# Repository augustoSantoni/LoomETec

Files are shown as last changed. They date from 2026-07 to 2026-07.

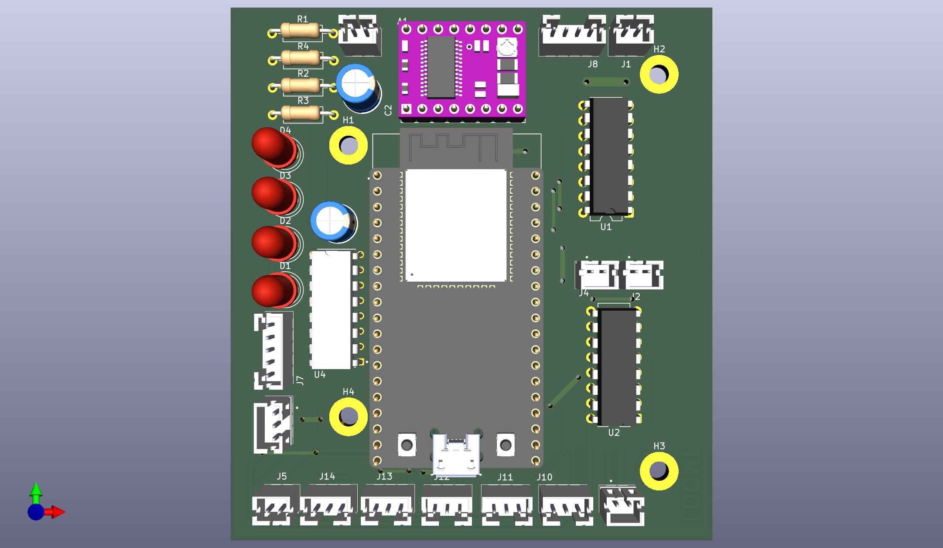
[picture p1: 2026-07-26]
Archivos/PCB/Archivos/LoomETec.png

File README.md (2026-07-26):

# 🧶 LOOM ETEC - Telar Automático con Sistema Jacquard





## 📖 Descripción del Proyecto

El proyecto **LOOM ETEC** se desarrolla en el marco del taller **AeroGlobETec**, que combina disciplinas como ciencias, electrónica, informática, mecánica y dibujo técnico.

### 🎯 Motivación

Este proyecto nace de una motivación personal, inspirada en la memoria de mi abuela, quien dedicó gran parte de su vida a tejer y donar sus creaciones a quienes más lo necesitaban. Tras su fallecimiento, surgió la idea de conmemorar su legado mediante la creación de un telar automático que perpetúe su espíritu altruista e integre conocimientos técnicos.

**Objetivo principal**: Automatizar el proceso de tejido para producir mantas destinadas a instituciones que asisten a recién nacidos en situación de vulnerabilidad.

### 🏗️ Tipos de Telares Implementados

#### 1️⃣ Telar Convencional

Compuesto por cuatro partes esenciales:

- **Caladores**: Varillas que levantan o bajan selectivamente los hilos de la urdimbre, creando una abertura (llamada "calada") por donde pasa la lanzadera con el hilo de la trama.
- **Peine**: Herramienta dentada que presiona y compacta el hilo de la trama después de cada pasada de la lanzadera.
- **Lanzadera**: Dispositivo que transporta el hilo de la trama a través de los hilos de la urdimbre para tejer la tela.
- **Plegador**: Mecanismo que enrolla la tela tejida, manteniendo la tensión y avanzando la urdimbre a medida que se teje.

#### 2️⃣ Telar Jacquard (31 columnas)

Una reversión del telar de Jacquard, máquina textil que utiliza patrones digitales (en lugar de tarjetas perforadas) para controlar automáticamente el levantamiento individual de hilos de urdimbre, permitiendo la creación de patrones complejos.

**Sistema de control**:
- **Eje X**: Motor PAP para movimiento horizontal (31 posiciones)
- **Eje Z**: Servomotor para selección arriba/abajo de cada hilo
- **Eje Y**: Motor DC para elevación del cabezal (calada)

---

## 🛠️ Tecnologías Utilizadas

### Software

#### **PlatformIO**
IDE profesional para desarrollo de sistemas embebidos. Proporciona gestión de bibliotecas, compilación cruzada y soporte para múltiples plataformas de hardware. Utilizado para programar el ESP32 con C++.

#### **Node-RED**
Herramienta de programación visual basada en flujos para conectar dispositivos IoT. Actúa como middleware entre la interfaz web y el broker MQTT, procesando las peticiones HTTP y transformándolas en comandos MQTT.

#### **MQTT (Mosquitto/HiveMQ Cloud)**
Protocolo de mensajería ligero para IoT. Permite la comunicación asíncrona entre el ESP32 y el servidor mediante topics (tópicos). Se puede usar Mosquitto localmente o HiveMQ Cloud para acceso remoto.

#### **Autodesk Fusion 360**
Software de modelado 3D CAD/CAM utilizado para diseñar las piezas mecánicas del telar, incluyendo soportes, engranajes y estructuras.

#### **Python 3.x + Tkinter**
Lenguaje de programación utilizado para desarrollar el **Editor de Trama**, una aplicación de escritorio que permite crear patrones de tejido de forma visual mediante una interfaz gráfica.

### Hardware

| Componente | Descripción | Cantidad |
|---|---|---|
| **ESP32 DevKit V1** | Microcontrolador principal con WiFi y Bluetooth integrado | 1 |
| **Motores DC** | Para lanzadera, peine y eje Y (elevación) | 3-4 |
| **Servomotores** | Para selección de hilos (Eje Z) en sistema Jacquard | 1 |
| **Motores PAP + DVR8825** | Motor paso a paso con driver para eje X (horizontal) y plegador | 2 |
| **Puente H L298N** | Controlador para motores DC bidireccionales | 2-3 |
| **Sensores Fin de Carrera** | Detección de posiciones límite (mínimo 7) | 7+ |
| **Fuente de Alimentación** | 12V 5A para motores | 1 |
| **Cables y Conectores** | Jumpers, borneras, conectores Dupont | Varios |

---

## 📋 Requisitos Previos

### Software a Instalar

1. **Visual Studio Code** con extensión **PlatformIO IDE**
2. **Node.js** (v14 o superior) para Node-RED
3. **Python 3.8+** para el Editor de Trama
4. **Mosquitto MQTT Broker** (opcional, para pruebas locales)

---

## 🚀 Guía de Instalación

### 1. Instalación de PlatformIO

1. Descargar e instalar [Visual Studio Code](https://code.visualstudio.com/)
2. Abrir VS Code y dirigirse a **Extensions** (Ctrl+Shift+X)
3. Buscar **PlatformIO IDE** e instalar
4. Reiniciar VS Code
5. Verificar instalación: debería aparecer un ícono de hormiga en la barra lateral

### 2. Instalación de Node-RED

```bash
# Instalar Node.js desde https://nodejs.org/

# Instalar Node-RED globalmente
npm install -g node-red

# Instalar nodos adicionales necesarios
cd ~/.node-red
npm install node-red-dashboard
npm install node-red-contrib-mqtt-broker

# Iniciar Node-RED
node-red

# Acceder a http://localhost:1880
```

### 3. Instalación de Python y Dependencias

```bash
# Verificar instalación de Python
python --version

# Instalar dependencias del Editor de Trama
pip install pillow
pip install tk

# En Linux/Mac, puede ser necesario instalar tkinter:
sudo apt-get install python3-tk  # Ubuntu/Debian
```

### 4. Configuración de MQTT Broker

#### Opción A: Mosquitto Local

```bash
# Windows: Descargar desde https://mosquitto.org/download/
# Linux:
sudo apt-get install mosquitto mosquitto-clients

# Iniciar servicio
sudo systemctl start mosquitto
sudo systemctl enable mosquitto

# Verificar que está corriendo en puerto 1883
netstat -tuln | grep 1883
```

#### Opción B: HiveMQ Cloud (Recomendado para acceso remoto)

1. Crear cuenta gratuita en [HiveMQ Cloud](https://www.hivemq.com/mqtt-cloud-broker/)
2. Crear un nuevo cluster
3. Anotar credenciales (URL, puerto, usuario, contraseña)
4. Actualizar configuración en `main.cpp` y flujos de Node-RED

---

## 🎨 Editor de Trama - Guía de Uso

### Iniciar el Editor

```bash
python Editor-Trama.py
```

### Funcionalidades Principales

#### 1. Crear un Patrón

- **Tamaño**: El editor trabaja con una cuadrícula de 24x24 píxeles por defecto
- **Colores**: 
  - Negro (patrón activo)
  - Blanco (fondo)
- **Pintar**: Click izquierdo para pintar, click derecho para borrar

#### 2. Pinceles Disponibles

| Pincel | Descripción |
|---|---|
| Punto | Pinta un solo píxel |
| Línea H | Línea horizontal de 3 píxeles |
| Línea V | Línea vertical de 3 píxeles |
| Cruz | Forma de cruz (5 píxeles) |
| Cuadrado | Cuadrado de 2x2 |
| Diagonal | Diagonal de 3x3 |

**Crear pincel personalizado**:
1. Click en "Crear Pincel"
2. Definir dimensiones (ej: 3x3)
3. Click en "Generar Cuadrícula"
4. Pintar el patrón deseado
5. "Guardar Pincel" → ingresar nombre → guardar archivo `.brush`

#### 3. Ajustar Tamaño del Lienzo

- **Agrandar**: Ctrl/Cmd + `+` o botón "Agrandar" (incrementa 4 filas)
- **Achicar**: Ctrl/Cmd + `-` o botón "Achicar" (reduce 4 filas, mínimo 24)

#### 4. Replicar Diseño

1. Crear un patrón base en las primeras 24 filas
2. Ingresar número de repeticiones (ej: 3)
3. Click en "Aplicar Replicación"
4. El patrón se repetirá verticalmente

#### 5. Exportar Patrón

##### Guardar como PNG (Ctrl/Cmd + S)
- Genera imagen con franjas de sincronización (patrón ajedrezado)
- Formato: 1 píxel = 1 hilo
- Incluye franjas cada 4 filas/columnas para alineación

##### Guardar como JSON (Ctrl/Cmd + J)
```json
{
  "dimensiones": [31, 100],
  "datos": [
    [0, 1, 0, 1, ...],
    [1, 0, 1, 0, ...],
    ...
  ]
}
```
- **IMPORTANTE**: Para el telar Jacquard, el patrón debe tener exactamente **31 columnas**
- 0 = hilo abajo (blanco), 1 = hilo arriba (negro)

#### 6. Atajos de Teclado

| Atajo | Acción |
|---|---|
| Ctrl/Cmd + Z | Deshacer |
| Ctrl/Cmd + Y | Rehacer |
| Ctrl/Cmd + L | Limpiar lienzo |
| Ctrl/Cmd + S | Guardar PNG |
| Ctrl/Cmd + J | Guardar JSON |
| Ctrl/Cmd + `+` | Agrandar lienzo |
| Ctrl/Cmd + `-` | Achicar lienzo |

---

## ⚡ Puesta en Marcha del Telar

### Paso 1: Conexiones del ESP32

#### Telar Convencional

```
LANZADERA:
  enaLanzadera → GPIO 29 (PWM)
  lanzadera1 → GPIO 28 (dirección 1)
  lanzadera2 → GPIO 20 (dirección 2)
  fdcLanzadera1 → GPIO 40 (fin de carrera izq)
  fdcLanzadera2 → GPIO 15 (fin de carrera der)

CALADORES:
  enaCaladores → GPIO 34 (PWM)
  caladores1 → GPIO 35 (subir)
  caladores2 → GPIO 27 (bajar)
  fdcCaladores → GPIO 16 (fin de carrera)

PEINE:
  enaPeine → GPIO 22 (PWM)
  peine1 → GPIO 24 (adelante)
  peine2 → GPIO 23 (atrás)
  fdcPeine1 → GPIO 13 (fin de carrera adelante)
  fdcPeine2 → GPIO 14 (fin de carrera atrás)

PLEGADOR:
  stepPlegador → GPIO 8 (pulsos)
  dirPlegador → GPIO 18 (dirección)
```

#### Telar Jacquard (adicional al convencional)

```
EJE X (Motor PAP):
  stepEjeX → GPIO 25
  dirEjeX → GPIO 26
  fdcEjeX_Home → GPIO 17 (posición inicial)

EJE Z (Servo):
  servoEjeZ → GPIO 19

EJE Y (Motor DC elevación):
  enaEjeY → GPIO 34 (PWM)
  ejeY_Up → GPIO 35
  ejeY_Down → GPIO 27
  fdcEjeY_Arriba → GPIO 16
  fdcEjeY_Abajo → GPIO 21
```

#### Diagrama de Conexión Puente H (ejemplo L298N)

```
ESP32           L298N          Motor DC
GPIO XX   →     ENA      →     (PWM control velocidad)
GPIO YY   →     IN1      →     (dirección)
GPIO ZZ   →     IN2      →     (dirección)
              OUT1/OUT2  →     Motor
GND       →     GND
12V       →     12V (fuente externa)
```

#### Conexión DVR8825 (Motor PAP)

```
ESP32           DVR8825        Motor PAP
GPIO XX   →     STEP
GPIO YY   →     DIR
             →  ENABLE (a GND o control)
12V fuente →    VMOT
GND        →    GND
             →  A1, A2, B1, B2 → Bobinas del motor
```

### Paso 2: Programar el ESP32

```bash
# Clonar el repositorio
git clone https://github.com/tu-usuario/loom-etec.git
cd loom-etec

# Abrir el proyecto en VS Code con PlatformIO
code .

# Configurar WiFi y MQTT en main.cpp (líneas 50-54)
String ssid = "TU_WIFI";
String password = "TU_PASSWORD";
const char* mqtt_server = "TU_BROKER_IP";  # localhost o IP de HiveMQ
const char* mqtt_user = "usuario";
const char* mqtt_pass = "contraseña";

# Compilar y subir (en VS Code)
# Click en el ícono "→" (PlatformIO: Upload) en la barra inferior
# O usar el atajo: Ctrl+Alt+U

# Monitorear salida serial
# Click en el ícono de enchufe (PlatformIO: Serial Monitor)
# O atajo: Ctrl+Alt+S
```

### Paso 3: Configurar Node-RED

```bash
# Iniciar Node-RED
node-red

# Abrir navegador en http://localhost:1880
```

#### Importar Flujo

1. Click en menú hamburguesa (☰) → **Import**
2. Seleccionar archivo:
   - `node-red-flujo-telar.json` (telar Jacquard con carga de patrón)
   - O `node-red-flujo-telar-simple.json` (telar convencional)
3. Click en **Import**

#### Configurar Broker MQTT en Node-RED

1. Doble click en cualquier nodo MQTT (ej: "mqtt_empezar")
2. Click en el lápiz junto a "Server"
3. Configurar:
   ```
   Server: localhost  (o IP del broker)
   Port: 1883
   Username: tu_usuario
   Password: tu_contraseña
   ```
4. Click en **Update** → **Done**
5. Click en **Deploy** (botón rojo arriba a la derecha)

#### Verificar Endpoints HTTP

Una vez desplegado, los siguientes endpoints estarán disponibles:

```
POST http://localhost:1880/api/empezar       - Iniciar tejido
POST http://localhost:1880/api/parar         - Detener tejido
POST http://localhost:1880/api/config/red    - Configurar WiFi
POST http://localhost:1880/api/config/patron - Cargar patrón JSON (solo Jacquard)
GET  http://localhost:1880/api/vueltas       - Obtener contador de vueltas
```

### Paso 4: Interfaz Web

#### Opción 1: Servidor Local Simple

```bash
# Navegar a la carpeta del proyecto
cd loom-etec

# Iniciar servidor HTTP simple con Python
python -m http.server 8000

# Abrir navegador en:
http://localhost:8000/index.html
```

#### Opción 2: Servidor Web Externo

Subir el archivo `index.html` a cualquier hosting web o usar:

```bash
# Con Node.js (live-server)
npm install -g live-server
live-server --port=8000
```

### Paso 5: Operación del Sistema

#### Para Telar Convencional

1. Verificar que el ESP32 esté conectado a WiFi (revisar Serial Monitor)
2. Abrir interfaz web en `http://localhost:8000/index.html`
3. Verificar conexión:
   - Debe mostrar vueltas: 0
   - Botones deben estar habilitados
4. Click en **▶ Iniciar** para comenzar tejido
5. El telar ejecutará la secuencia automáticamente
6. Click en **■ Detener** para pausar

#### Para Telar Jacquard

1. Crear patrón en Editor de Trama (31 columnas)
2. Exportar como JSON (Ctrl+J)
3. Abrir interfaz web
4. En "Cargar patrón":
   - Click en zona de arrastre o seleccionar archivo
   - Elegir el archivo `.json` generado
   - Click en **Subir patrón al telar**
   - Esperar confirmación "🟢 Patrón subido correctamente"
5. Click en **▶ Iniciar**
6. El telar ejecutará el patrón columna por columna

---

## 🔧 Calibración y Ajustes

### Calibración del Sistema Jacquard

En `main.cpp`, ajustar las siguientes constantes según tu hardware:

```cpp
// Línea 60-65
#define PASOS_POR_COLUMNA 200    // Ajustar según distancia entre columnas
#define DELAY_PASO_X 800         // Velocidad del motor PAP (microsegundos)
#define SERVO_POS_ABAJO 45       // Posición servo para dejar hilo abajo
#define SERVO_POS_ARRIBA 135     // Posición servo para fijar hilo arriba
#define SERVO_DELAY 150          // Tiempo de movimiento del servo
```

### Ajuste de Velocidades de Motores

```cpp
// Línea 115-120
ledcWrite(PWM_LANZADERA, 200);  // 0-255: ajustar velocidad lanzadera
ledcWrite(PWM_PEINE, 200);      // 0-255: ajustar velocidad peine
ledcWrite(PWM_EJE_Y, 200);      // 0-255: ajustar velocidad elevación
```

### Tiempos de Estabilización

```cpp
// Línea 70-75
#define DELAY_TEJER 500           // Pausa entre ciclos completos
#define TIEMPO_ESTABILIDAD 200    // Pausa tras cada movimiento
#define TIEMPO_ESPERA_FDC 15000   // Timeout para sensores de fin de carrera
```

---

## 📡 Arquitectura del Sistema

```
┌─────────────────┐
│  Interfaz Web   │ ← Usuario interactúa
│  (index.html)   │
└────────┬────────┘
         │ HTTP (fetch)
         ▼
┌─────────────────┐
│   Node-RED      │ ← Middleware (localhost:1880)
│  (flujo.json)   │
└────────┬────────┘
         │ MQTT
         ▼
┌─────────────────┐
│ Broker MQTT     │ ← Mosquitto/HiveMQ
│  (puerto 1883)  │
└────────┬────────┘
         │ WiFi
         ▼
┌─────────────────┐
│     ESP32       │ ← Control de hardware
│   (main.cpp)    │
└────────┬────────┘
         │ GPIO
         ▼
┌─────────────────┐
│ Motores/Sensores│ ← Sistema mecánico
└─────────────────┘
```

---

## 🐛 Solución de Problemas

### ESP32 no se conecta a WiFi

```cpp
// Verificar credenciales en main.cpp
String ssid = "NOMBRE_EXACTO";  // Sin espacios extra
String password = "PASSWORD_EXACTA";

// Verificar en Serial Monitor:
// - "Conectando a SSID..."
// - "WiFi conectado"
// - "IP: xxx.xxx.xxx.xxx"
```

### Node-RED no recibe mensajes MQTT

1. Verificar broker MQTT está corriendo:
   ```bash
   sudo systemctl status mosquitto
   # o
   mosquitto -v
   ```

2. Probar conexión con mosquitto_sub:
   ```bash
   mosquitto_sub -h localhost -t "empezar" -v
   ```

3. Verificar configuración de broker en Node-RED coincide con ESP32

### Sensores de fin de carrera no funcionan

```cpp
// Verificar lógica de activación (línea 30)
#define FDC_PRESIONADO LOW  // Cambiar a HIGH si usa pull-down

// Agregar resistencias pull-up/down según tipo de sensor
```

### Servo no se mueve correctamente

```cpp
// Calibrar posiciones del servo (línea 62-63)
#define SERVO_POS_ABAJO 45      // Probar valores entre 0-180
#define SERVO_POS_ARRIBA 135    // Ajustar según rango del servo

// Verificar alimentación del servo (5V, GND correcto)
```

### Motor PAP pierde pasos

```cpp
// Aumentar delay entre pasos (línea 61)
#define DELAY_PASO_X 1200  // Valor más alto = movimiento más lento pero preciso

// Verificar:
// - Conexión de bobinas del motor
// - Configuración de micropasos en DVR8825
// - Alimentación suficiente (12V)
```

---

## 📊 Tópicos MQTT

### Publicados por ESP32

| Tópico | Payload | Descripción |
|---|---|---|
| `vuelta` | Número entero | Contador de vueltas completadas |

### Suscritos por ESP32

| Tópico | Payload | Descripción |
|---|---|---|
| `empezar` | `"1"` | Iniciar tejido |
| `parar` | `"1"` | Detener tejido |
| `config/red` | JSON: `{"ssid": "...", "password": "..."}` | Configurar WiFi |
| `config/patron` | JSON: `{"filename": "...", "content": "{...}"}` | Cargar patrón (Jacquard) |

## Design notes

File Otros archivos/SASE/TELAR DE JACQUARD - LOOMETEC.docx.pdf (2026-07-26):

LOOMETEC: TELAR DE JACQUARD SANTONI, Augusto - a.santoni@alumno.etec.um.edu.ar - 3ro Electrónica FURCI, Patricia Elizabeth - patricia.furci@etec.um.edu.ar - Docente a cargo.

### 1. INTRODUCCIÓN:

El proyecto se desarrolla en el marco
del taller AeroGlobETec que combina
disciplinas | como | ciencias, | electrónica,
informática, mecánica y dibujo técnico.

El presente proyecto nace de la motivación de automatizar el proceso de tejido para producir mantas destinadas a instituciones que asisten a recién nacidos en situación de vulnerabilidad, con el propósito de contribuir solidariamente a quienes más lo necesitan.

A diferencia de un telar de calado simple, este proyecto implementa un sistema inspirado en el mecanismo Jacquard, que permite un control selectivo e individual de los hilos de la urdimbre. En lugar de tarjetas perforadas, se emplea un sistema de movimiento en tres ejes: uno que recorre los soportes de hilos, otro que selecciona cuáles serán elevados en la próxima calada y aquel que los eleva, posibilitando la generación de patrones complejos de manera automatizada.

Un telar convencional se compone de cuatro partes esenciales: Caladores: varillas que levantan o bajan selectivamente los hilos de la urdimbre, creando la "calada". Peine: herramienta dentada que compacta el hilo de la trama tras cada pasada. Lanzadera: dispositivo que transporta el hilo de la trama. Plegador: mecanismo que enrolla la tela tejida manteniendo la tensión.

### 2. OBJETIVOS:

Objetivos generales:
El objetivo central es materializar el telar automático y dejarlo en pleno funcionamiento, incorporando además una aplicación de escritorio para el diseño de patrones y un sistema de control de procesos en tiempo real. El desarrollo se plantea en etapas: primero en modo de calado simple y luego en modo de calado selectivo.
Objetivos específicos:
Adquirir un conocimiento profundo sobre el funcionamiento de los telares de Jacquard, comprendiendo cada una de sus
partes | y | su | integración. | Dominar
herramientas como Autodesk Fusion 360 para el diseño tridimensional y PlatformIO en Visual Studio Code para el desarrollo del firmware. El sistema será controlado por un microcontrolador ESP32 NODEMCU-32S, y se desarrollará una PCB propia que integrará: dos motores PAP Nema 17 con drivers DRV8825 (soporte de hilos y plegador); un motor 28BYJ-48 con módulo ULN2003 y un micro servo sg90 (selección de hilos); cuatro motores DC con L293D (lanzadera, calador y peine); un convertidor step-down para operar con una única fuente de 12 V; y seis fines de carrera. La
comunicación | y | control | remoto | se
gestionarán mediante el broker Mosquitto, protocolo MQTT y Node-RED, conectado a una interfaz web. Se incorporará también un sistema de control de procesos basado en el ATmega328P y una aplicación de escritorio para el diseño de patrones de tejido.

### 3. DESARROLLO:

Primero se investigó en profundidad el funcionamiento del telar e idearon los sistemas correspondientes a cada una de sus partes. Para movimientos con límites precisos se emplearon motores DC con finales de carrera; para posicionamiento controlado, motores PAP o servomotores. Se realizaron diagramas técnicos de cada sistema de movimiento.

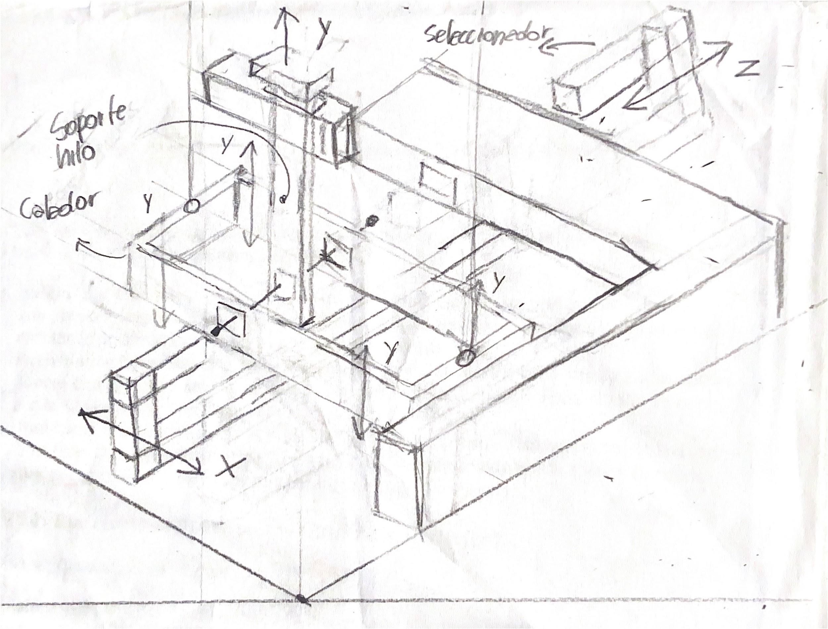
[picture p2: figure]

Diagrama del calador con sus respectivas partes y los ejes de movimiento
El sistema electrónico fue diseñado y desarrollado en su totalidad. Se elaboró el esquemático y el layout de una PCB que centraliza el control del telar, integrando todos los drivers y módulos.

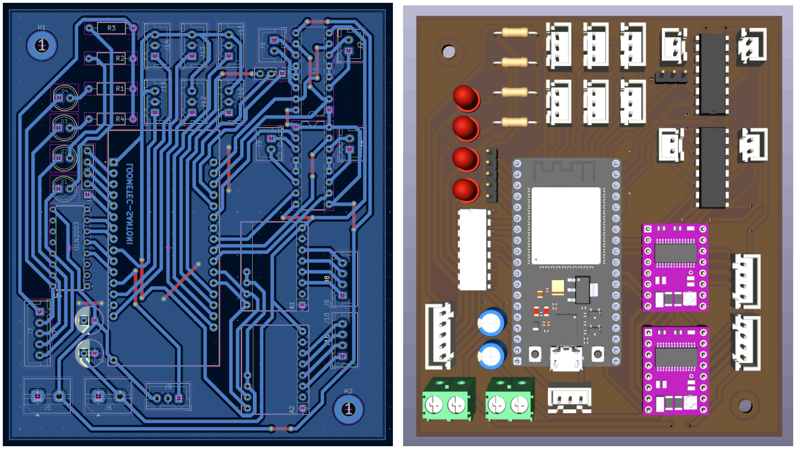
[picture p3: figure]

Prototipo de la placa para el telar
El | firmware | se | desarrolló | en
PlatformIO, implementando comunicación MQTT con broker Mosquitto, integrado con Node-RED y una interfaz web de monitoreo y control remoto. Donde se mantendrá un registro histórico de variables del proceso (patrón utilizado, centímetros producidos, fecha y hora) para facilitar el diagnóstico de fallas.

Se desarrolló una aplicación de escritorio (PC) para el diseño de patrones de tejido. La herramienta permite construir gráficamente una cuadrícula que define qué hilos de la urdimbre serán elevados en cada pasada. Al exportar, el sistema aplica
automáticamente | restricciones | de
estabilidad estructural que garantizan la cohesión de la tela resultante sin intervención del usuario. El patrón validado se exporta en formato JSON, listo para ser interpretado por el firmware del telar.

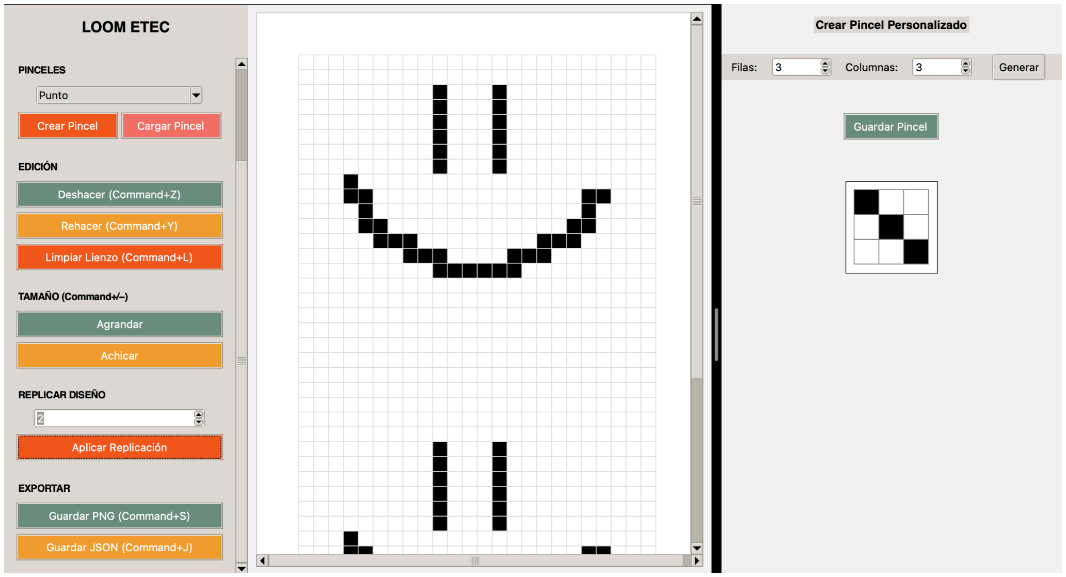
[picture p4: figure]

Interfaz del editor de trama junto con el editor de pinceles

Se proyecto un sistema de gestión de procesos basado en el ATmega328P, con sensores de tensión del hilo (FSR),
temperatura | (NTC/DHT) | y | humedad
ambiente (DHT) para implementarlo en el futuro. Cuando un parámetro supera el umbral definido, el sistema generaría alertas simultáneas en la interfaz Node-RED y mediante un bot de Telegram, permitiendo respuesta inmediata incluso de forma remota.

En Autodesk Fusion 360 se realizaron
los | modelos | 3D | correspondientes,
adaptables al sistema electrónico. Y una animación del funcionamiento del nuevo mecanismo basado en el sistema de Jacquard.

### 4. RESULTADOS:

- Diseño completo de la PCB con todos sus componentes integrados.

- Sistema de comunicación MQTT con Mosquitto, Node-RED e interfaz web para control remoto.
- Aplicación de escritorio para diseño de patrones con exportación en JSON y
restricciones | automáticas | de
estabilidad estructural.
- Ideación de un sistema de monitoreo
con | ATmega328P, | sensores FSR,
NTC/DHT y alertas vía Node-RED y
Telegram | para | su | futura
implementacion.
- Modelo tridimensional completo de la parte mecánica del telar y animación del funcionamiento del sistema de jacquard y del telar simple. A las cuales se puede acceder desde el siguiente link: Animaciónes-Telar. (https://drive.google.com/drive/folders/128MVLVmaG0PWlYvmhCZqHiCv8H61GHJZ?usp=sharing)

### 5. DISCUSIONES Y CONCLUSIONES:

El mayor desafío del proyecto ha sido la articulación entre el diseño y la materialización. Si bien el sistema completo —electrónico, informático y estructural— ha sido desarrollado y documentado en detalle, la concreción física del telar depende de la financiación que actualmente se está gestionando. Es esperable que, una vez materializado, el telar presente fallas e inconvenientes que deberán identificarse y corregirse de forma iterativa, siendo este proceso de ajuste una parte natural e inevitable del desarrollo de cualquier sistema de esta complejidad.

Como proyección futura, se propone la aplicación material del sistema de control de procesos ya ideado; ampliar la aplicación de patrones con simulación visual de la tela resultante, edición de diseños JSON previamente exportados y envío directo del patrón al telar desde la aplicación. Además, se contempla una interfaz web más completa con gestión de patrones remota, calibración automática de la tensión del hilo al inicio de cada sesión y un modo de prueba de patrón en seco para validar diseños antes de tejer, reduciendo el desperdicio de material.

En conclusión, esta experiencia ha
sido | altamente | enriquecedora,
proporcionando herramientas valiosas y un aprendizaje significativo. Poder pasar de una idea a un proyecto y encaminarse a concretar una máquina capaz de tejer mantas para
quienes | más | las | necesitan es una
oportunidad incomparable.

### 6. FUENTES:

[1] JANDER, R. (s.f.). R. Jander's personal
website. | Recuperado | de
https://r.jander.me.uk/
[2] TEXTALKS. (s.f.). Textalks YouTube
channel. | Recuperado | de
https://www.youtube.com/@textalks
[3] EDMUNDS, Susan T. (2020). Picturing Homeric Weaving. The Center for Hellenic
Studies. | Recuperado | de
https://chs.harvard.edu/susan-t-edmunds-picturing-homeric-weaving/
[4] TOMASZ ZAJĄC (31 ene 2013). LEGO Mindstorms NXT Loom Machine. Disponible en:
https://youtu.be/IPIJsdvDjsc?si=PrbSpxk5nL Od-ASY
[5] ¿CÓMO SE ELABORÓ? TEJIDO JACQUARD (https://www.youtube.com/watch?v=K6NgMNvK52A) , canal de YouTube del Museo Victoria y Alberto, 8 de octubre de 2015.
[6] PATRONES DE PROGRAMACIÓN: LA
HISTORIA | DEL | TELAR | JACQUARD, (https://www.scienceandindustrymuseum.org.uk/objects-and-stories/jacquard-loom)
publicación | del Science and Industry
Museum (Museo de Ciencia e Industria) de Manchester, 25 de junio de 2019.

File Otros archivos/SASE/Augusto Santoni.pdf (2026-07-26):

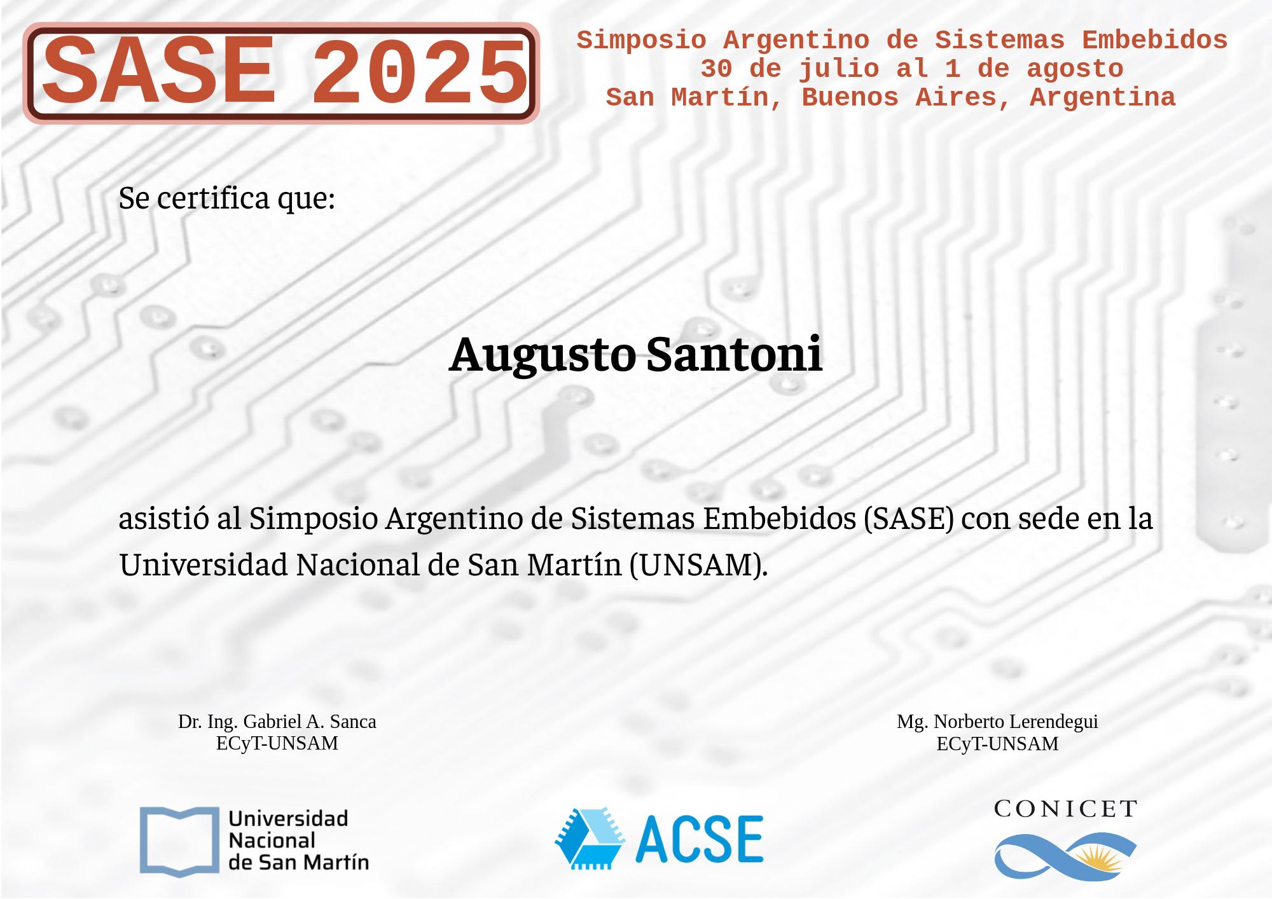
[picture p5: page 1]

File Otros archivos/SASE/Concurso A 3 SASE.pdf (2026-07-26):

“Proyectos de asignaturas de estudiantes de nivel secundario.

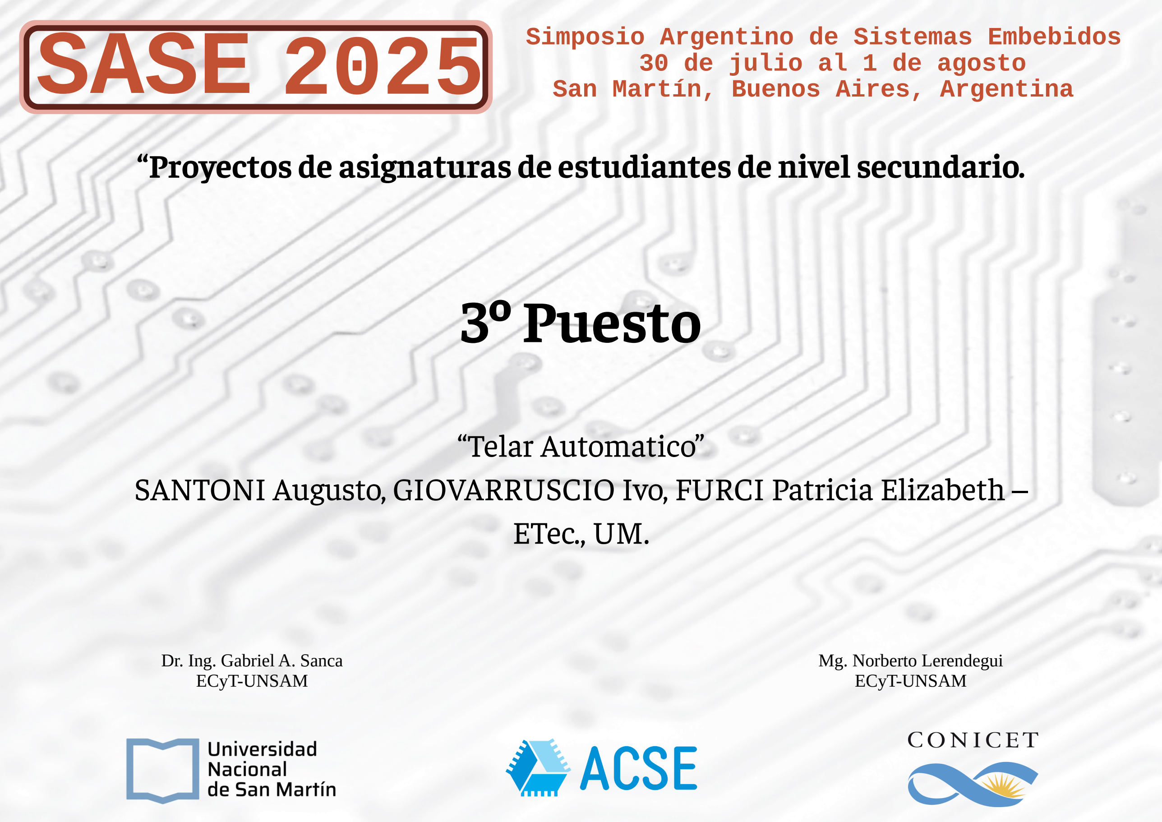
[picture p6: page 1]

Mg. Norberto Lerendegui
ECyT-UNSAM

Dr. Ing. Gabriel A. Sanca
ECyT-UNSAM
Simposio Argentino de Sistemas Embebidos SASE 2025 | 30 de julio al 1 de agosto

San Martín, Buenos Aires, Argentina

# 3º Puesto

## “Telar Automatico” SANTONI Augusto, GIOVARRUSCIO Ivo, FURCI Patricia Elizabeth –

ETec., UM.

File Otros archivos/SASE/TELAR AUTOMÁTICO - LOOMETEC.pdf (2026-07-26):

LOOMETEC: TELAR AUTOMÁTICO

SANTONI, Augusto - a.santoni@alumno.etec.um.edu.ar - 2do A GIOVARRUSCIO, Ivo - i.giovarruscio@alumno.etec.um.edu.ar - 4to Informática FURCI, Patricia Elizabeth - patricia.furci@etec.um.edu.ar - Docente a cargo.

### 1. INTRODUCCIÓN:

El proyecto se desarrolla en el
marco del taller AeroGlobETec que combina disciplinas como ciencias, electrónica, informática, mecánica y dibujo técnico.

El presente proyecto nace de una motivación personal, inspirada en la memoria de mi abuela, quien dedicó gran parte de su vida a tejer y donar sus
creaciones | a | quienes | más | lo
necesitaban. Tras su fallecimiento el año pasado, surgió la idea de conmemorar su legado, mediante la creación de un telar automático que no solo perpetúe su espíritu altruista, sino que también
integre | conocimientos | técnicos | de
manera innovadora. Este telar tiene como propósito automatizar el proceso
de | tejido | para | producir | mantas
destinadas a instituciones que asisten a
recién | nacidos | en | situación | de
vulnerabilidad.
Un | telar | convencional | se
compone de cuatro partes esenciales, cada una con una función clave para el proceso de tejido: Caladores: Son
varillas | que | levantan | o | bajan
selectivamente los hilos de la urdimbre, creando una abertura (llamada "calada") por donde pasa la lanzadera con el hilo de la trama. Peine: El peine es una herramienta dentada que se usa para presionar y compactar el hilo de la trama después de cada pasada de la lanzadera. Lanzadera: La lanzadera es un dispositivo que transporta el hilo de la trama a través de los hilos de la urdimbre para tejer la tela. Plegador: El plegador es el mecanismo que enrolla la tela
tejida, | manteniendo | la | tensión | y
avanzando la urdimbre a medida que se teje.

### 2. OBJETIVOS:

Objetivos generales:

En la fase inicial del proyecto, se busca desarrollar un banco de pruebas que integre y sincronice los componentes
fundamentales del telar: | caladores,
peine, | lanzadera | y | plegador;
garantizando su correcto funcionamiento en conjunto.

Objetivos específicos:

Adquirir un conocimiento profundo sobre
el | funcionamiento | de | los telares,
comprendiendo cada una de sus partes y su integración. Se busca dominar
herramientas | especializadas | como
Autodesk Fusion 360 para el diseño tridimensional, y PlatformIO en Visual Studio Code, junto con plataformas de
mensajería | como | HiveMQ | Cloud,
protocolos como MQTT y herramientas de programación visual basadas en flujos como Node-RED, para el desarrollo informático del proyecto. Además, se empleará el ESP32 DevKit V1 para controlar motores de corriente continua (DC) y paso a paso (PAP), utilizando drivers como el Puente H para motores DC y el DVR8825 para motores PAP, así como sensores como los fines de carrera. Con estas herramientas, se diseñarán e implementarán sistemas electrónicos, informáticos y mecánicos de manera integrada.

### 3. DESARROLLO:

Primero debíamos investigar el funcionamiento del telar e idear un sistema para cada una de sus partes, empleando motores DC equipados con sensores de fin de carrera para controlar con precisión el inicio y el fin de los movimientos, así como motores PAP cuando las características del sistema lo requerían. En el proceso, se realizaron diagramas técnicos que representaban el funcionamiento de cada componente, como el que se muestra a continuación:

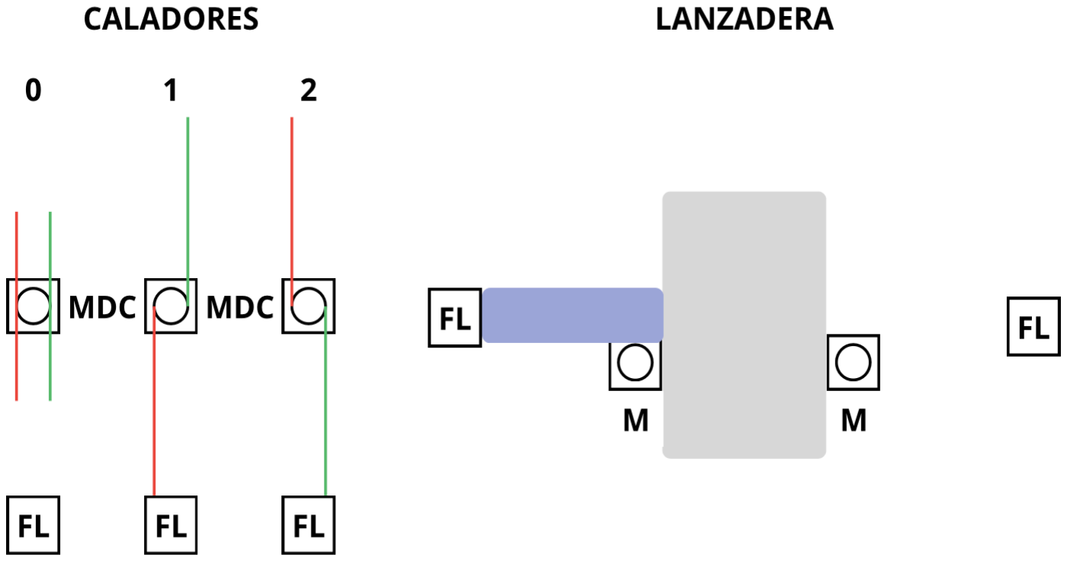
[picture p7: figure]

Posteriormente, se determinó la cantidad de componentes necesarios y
se | asignaron | a | los | pines
correspondientes del microcontrolador.
Esta | planificación | | nos | permitió
desarrollar el código. El cual se llevó a cabo en Visual Studio Code utilizando PlatformIO. Se implementó un servicio de broker mediante HiveMQ Cloud para conectar el microcontrolador, empleando el protocolo de comunicación MQTT, integrado con Node-RED.
En | Autodesk | Fusion | 360
realizamos dos modelos 3D. Uno adaptable al sistema electrónico, con el propósito de ilustrar de manera clara y accesible el funcionamiento de cada parte del telar con la intención de imprimirlos para su implementación en el banco de pruebas. Y el otro para realizar una animación donde se demuestra cómo se integran y comunican todas estas partes de forma eficiente.

### 4. RESULTADOS:

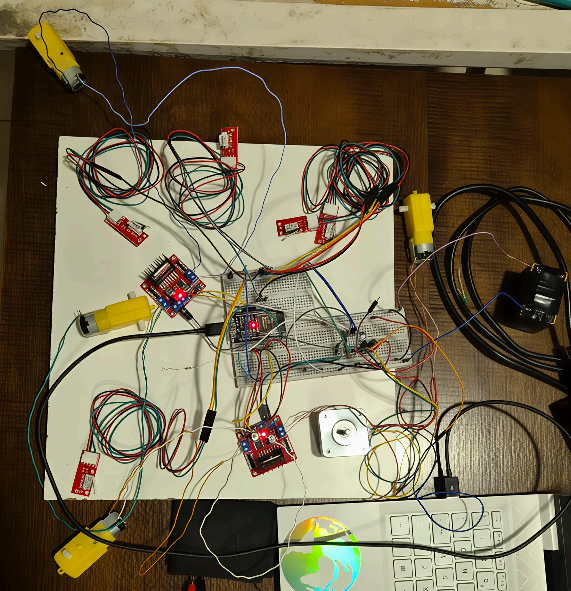
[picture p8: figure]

Sistema electrónico del telar (ESP32, motores DC y paso a paso y fines de carrera)

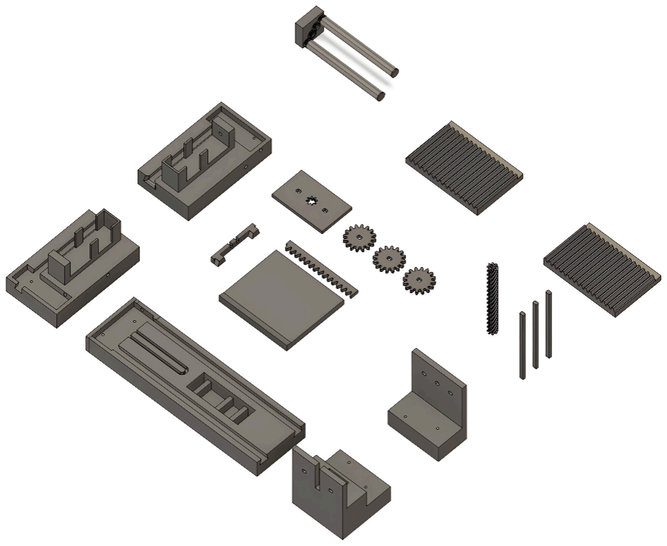
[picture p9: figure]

Modelo tridimensional de la parte mecánica del telar que no pudimos imprimir al tiempo de la entrega del informe

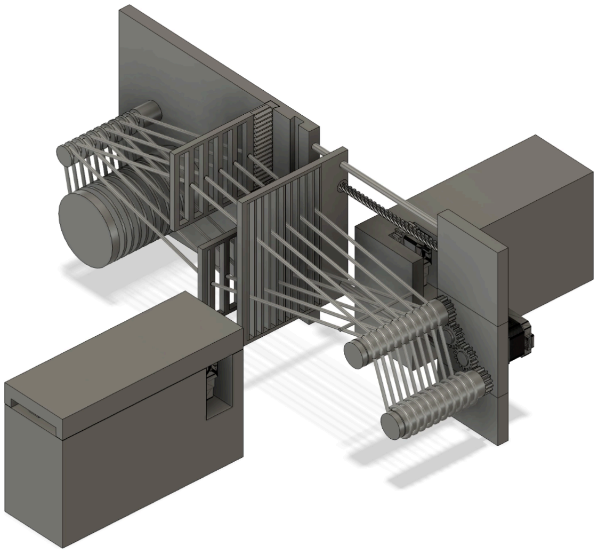
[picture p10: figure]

Diseño tridimensional del telar para mostrar el funcionamiento de su mecanismo

A continuación se adjuntan links para acceder a más información sobre el proyecto:

1. Código Final del Proyecto (https://drive.google.com/drive/folders/1bpm9aZeXHoDyKulyQSnF2jZQobiZWJnf?usp=drive_link)
2. Animación Telar Digital (https://drive.google.com/file/d/1vYuAYyDnDdPBkydJ6CRCXGrwoH7npYBo/view?usp=drive_link)
3. Videos del Sistema Electrónico (https://drive.google.com/drive/folders/1xzQIi9Cb-TToxrK4wxwNaI4A_W0bQ0Gt?usp=sharing)
5. | DISCUSIONES | Y
CONCLUSIONES:
El | mayor | inconveniente | del
proyecto tuvo relación al tiempo, En un determinado momento tuvimos que evaluar y redefinir nuestros objetivos. El proyecto era muy ambicioso para los plazos que teníamos; no obstante esto, logramos desarrollar un banco de pruebas operativo y un sistema basado
en | Node-RED | para | su | control,
acompañado | de | animaciones | que
muestran su funcionamiento potencial.
El | proyecto | es | perfectible.
Identificamos luego de los logros que los caladores podrían complejizarse para poder
desarrollar | patrones | de | tejidos | mas
complejos. También que la herramienta Node-RED presenta limitaciones para la implementación de funcionalidades mas
avanzadas. | Para | superar | estas
restricciones, se propone implementar un sistema de control independiente para cada hilo del telar y desarrollar una interfaz web con Paho MQTT para gestionar patrones de forma remota, mejorando la accesibilidad.

En conclusión, esta experiencia ha
sido | altamente | enriquecedora,
proporcionando herramientas valiosas y un aprendizaje significativo tanto a nivel técnico como colaborativo. Poder pasar de la actividad cotidiana de mi abuela a una idea para luego llevarla a proyecto y así concretar una máquina que en algún momento sea capaz de tejer es una oportunidad incomparable. Como equipo, participar en este tipo de iniciativas ha
fortalecido | el | aprendizaje | activo,
promoviendo la creatividad y el trabajo conjunto.

### 6. FUENTES:

[1] JANDER, R. (s.f.). R. Jander's personal website. Recuperado de https://r.jander.me.uk/
[2] TEXTALKS. (s.f.). Textalks YouTube
channel. | Recuperado | de
https://www.youtube.com/@textalks
[3] | EDMUNDS, | Susan | T. (2020).
Picturing Homeric Weaving. The Center for Hellenic Studies. Recuperado de https://chs.harvard.edu/susan-t-edmunds-picturing-homeric-weaving/ (https://chs.harvard.edu/susan-t-edmunds-picturing-homeric-weaving/)

[4]: TOMASZ ZAJĄC (31 ene 2013),
LEGO | Mindstorms | NXT | Loom
Machine. | Disponible | en:
https://youtu.be/IPIJsdvDjsc?si=PrbSpxk5 nLOd-ASY (https://youtu.be/IPIJsdvDjsc?si=PrbSpxk5nLOd-ASY)

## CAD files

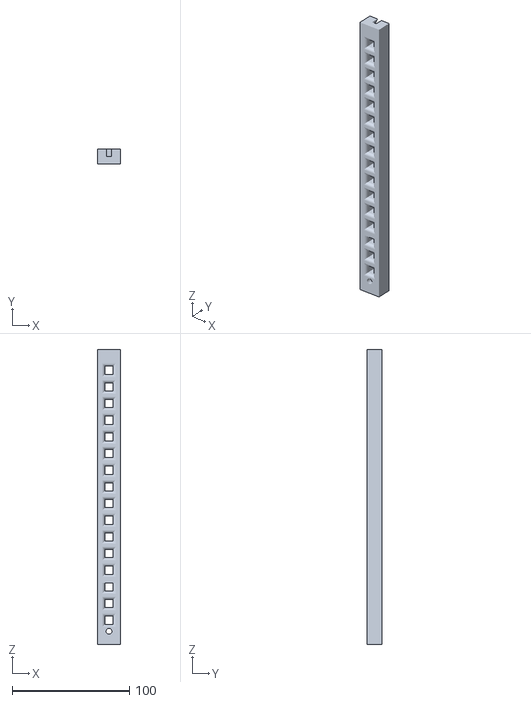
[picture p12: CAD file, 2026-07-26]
Archivos/LoomETec-Jacquard/Diseños/Calador/Base1.stl
19.8 x 13.2 x 252.0

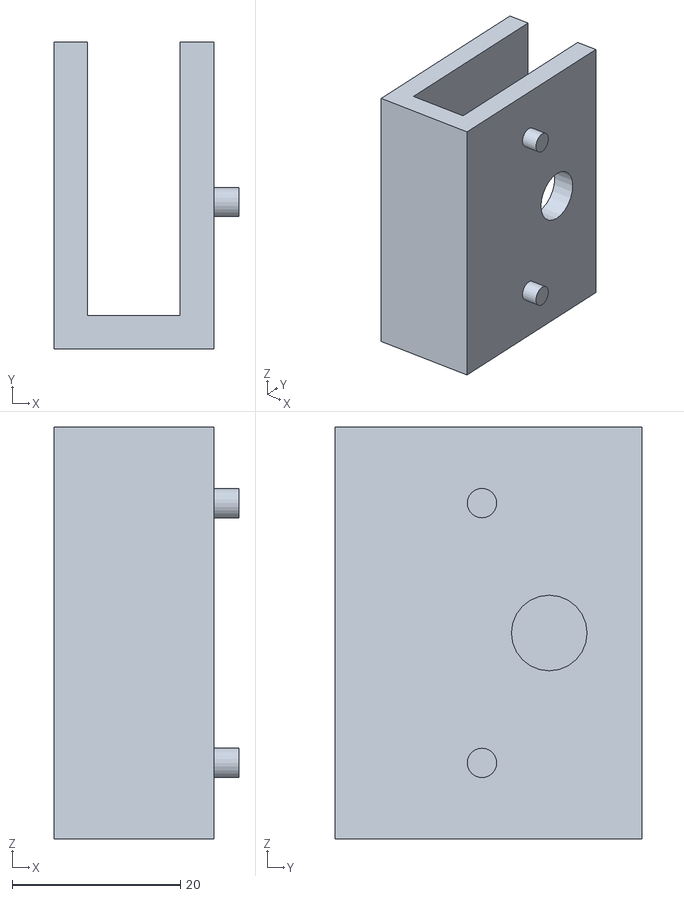
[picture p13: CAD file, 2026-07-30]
Archivos/LoomETec-Jacquard/Diseños/ChasisMovEjeX.stl
22.0 x 36.5 x 49.0

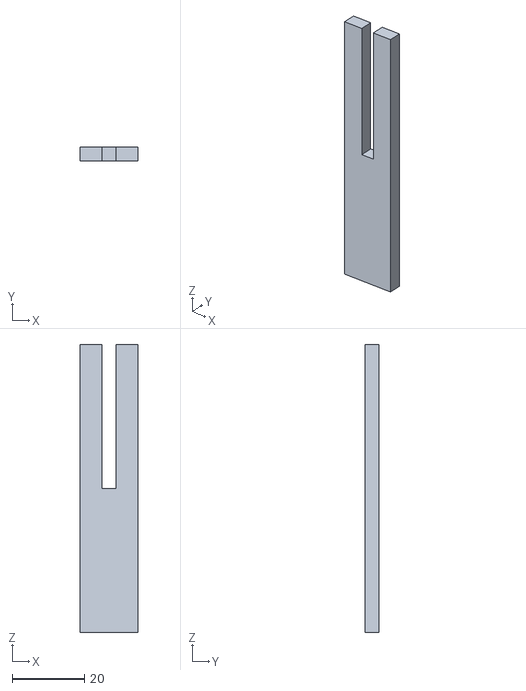
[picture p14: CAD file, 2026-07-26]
Archivos/LoomETec-Jacquard/Diseños/Lanza/ConectorLanza.stl
16.0 x 4.00 x 80.0

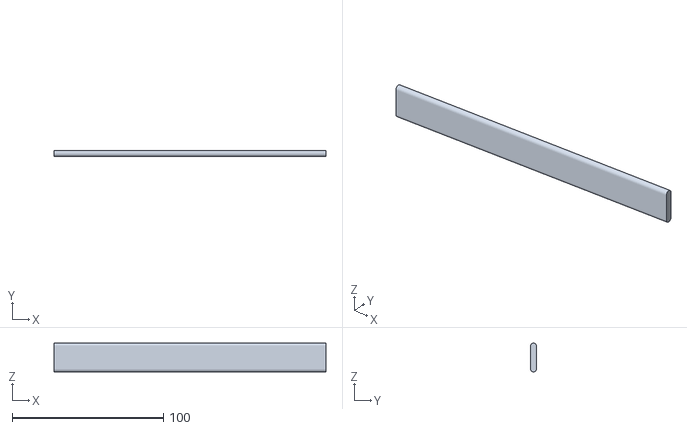
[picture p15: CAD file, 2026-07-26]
Archivos/LoomETec-Jacquard/Diseños/Peine/GuiaPeine.stl
180.0 x 4.00 x 19.0

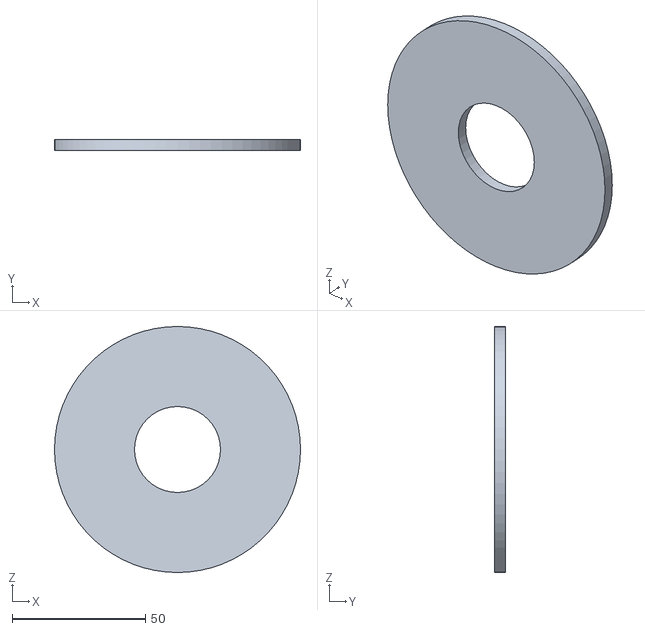
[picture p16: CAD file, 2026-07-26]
Archivos/LoomETec-Jacquard/Diseños/Plegador-SoporteHilo/SeparadorHilo.stl
92.2 x 4.00 x 92.2

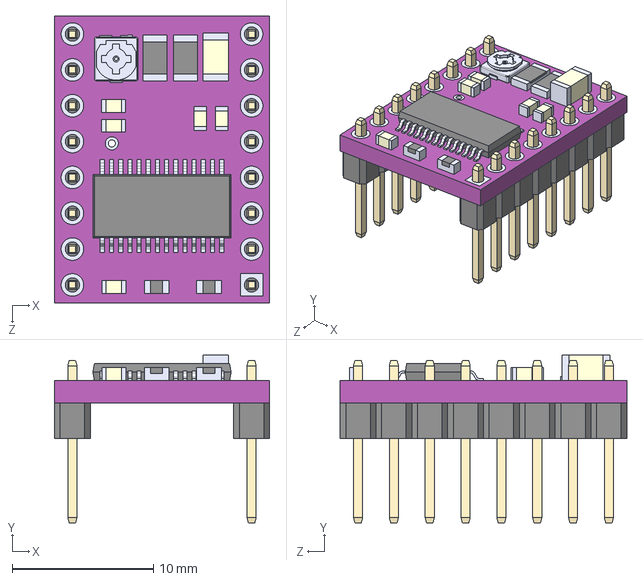
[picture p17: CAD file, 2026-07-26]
Archivos/PCB/LIBRERIAS /Archivos 3d/DRV8825 STEPPER MOTOR DRIVER CARRIER--3DModel-STEP-1.STEP
15.2 x 11.9 x 20.3 mm

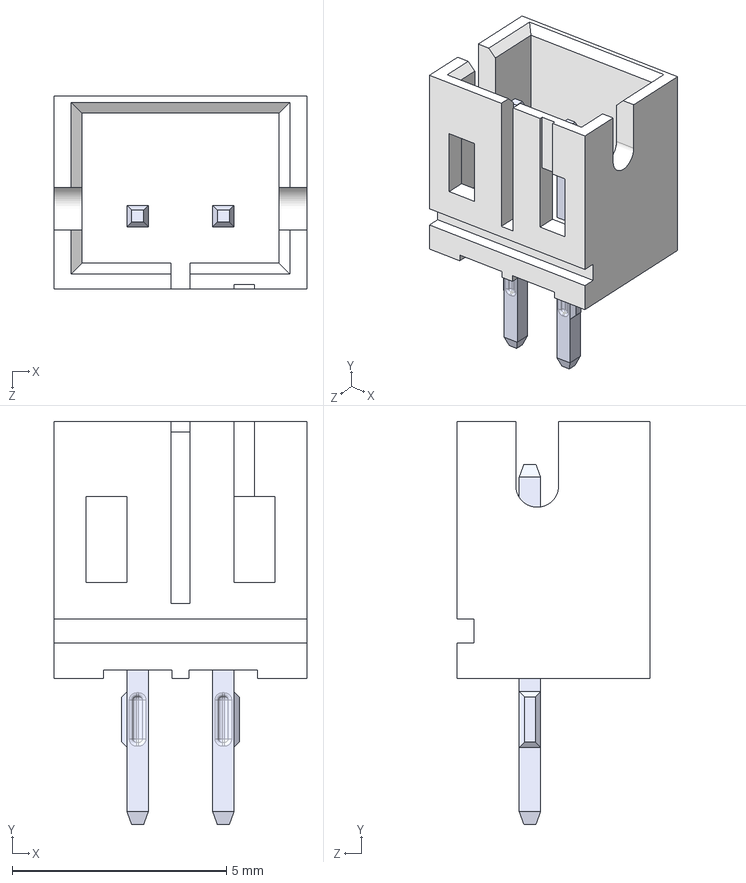
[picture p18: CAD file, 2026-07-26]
Archivos/PCB/LIBRERIAS /Huellas/B2B-PH-K-S/B2B-PH-K-S.step
5.90 x 9.40 x 4.50 mm

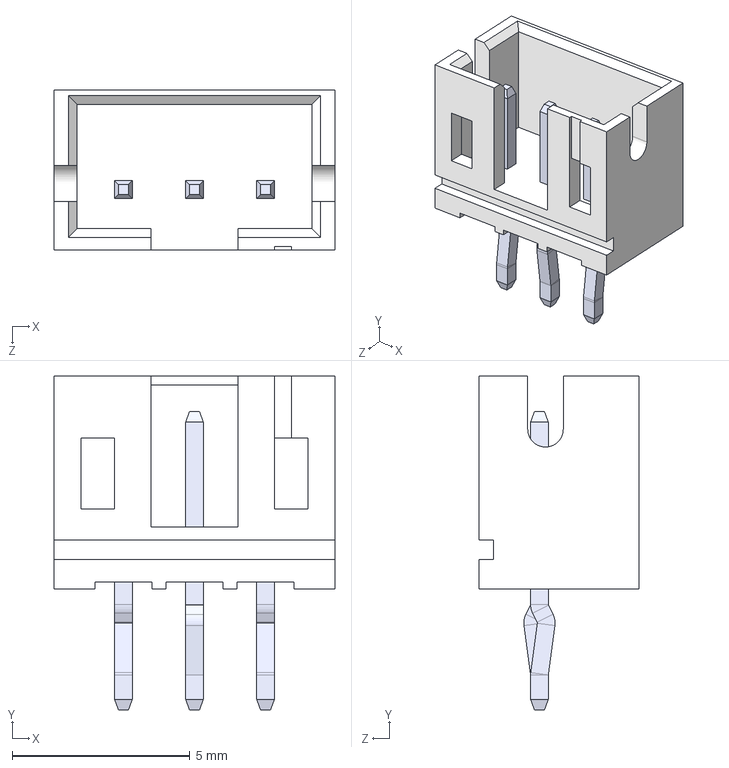
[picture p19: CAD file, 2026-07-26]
Archivos/PCB/LIBRERIAS /Huellas/B3B-PH-K-S/B3B-PH-K-S.step
7.90 x 9.40 x 4.50 mm
pin x 3

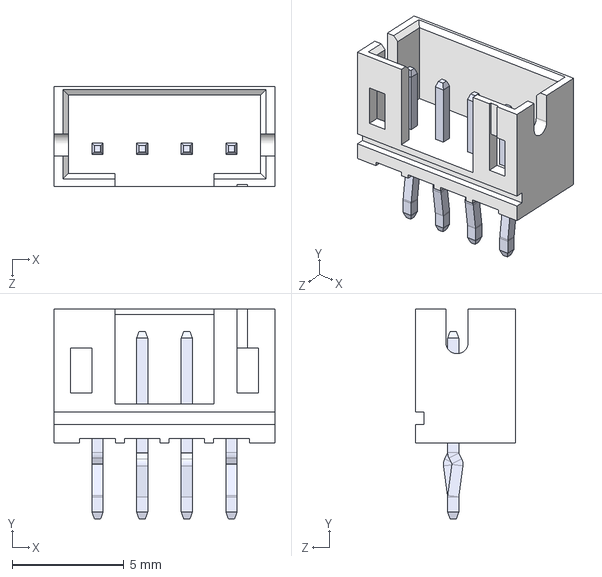
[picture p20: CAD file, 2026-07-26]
Archivos/PCB/LIBRERIAS /Huellas/B4B-PH-K-S/B4B-PH-K-S.step
9.90 x 9.40 x 4.50 mm
pin x 4

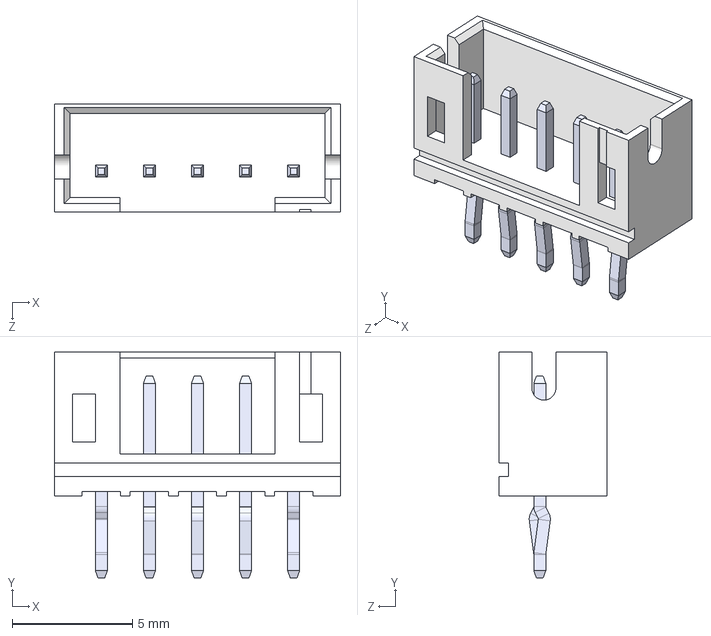
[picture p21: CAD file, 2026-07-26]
Archivos/PCB/LIBRERIAS /Huellas/B5B-PH-K-S/B5B-PH-K-S.step
11.9 x 9.40 x 4.50 mm

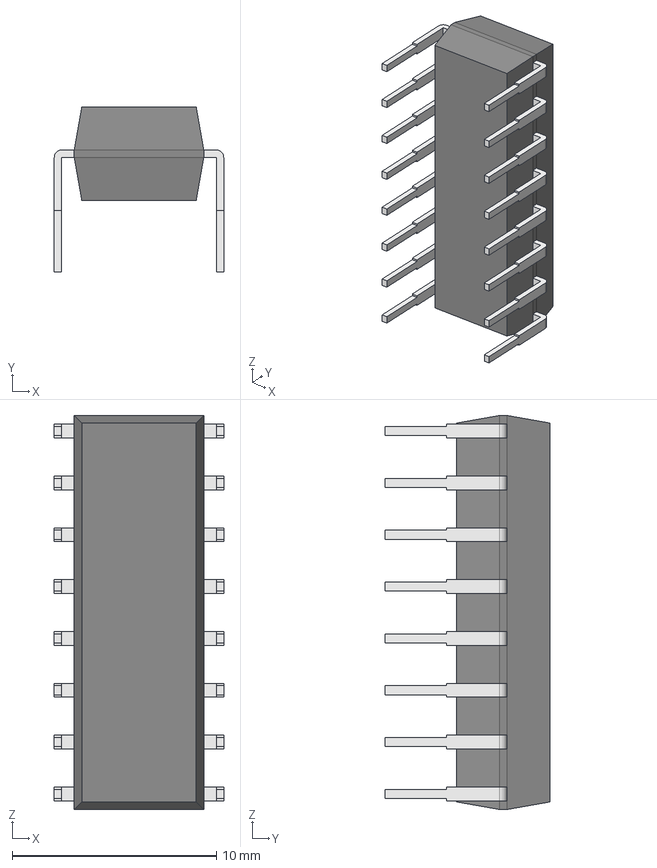
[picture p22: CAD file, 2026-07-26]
Archivos/PCB/LIBRERIAS /Huellas/ULN2003AN/ULN2003AN.step
8.31 x 8.08 x 19.3 mm
Body001 (Mirror #1) x 9

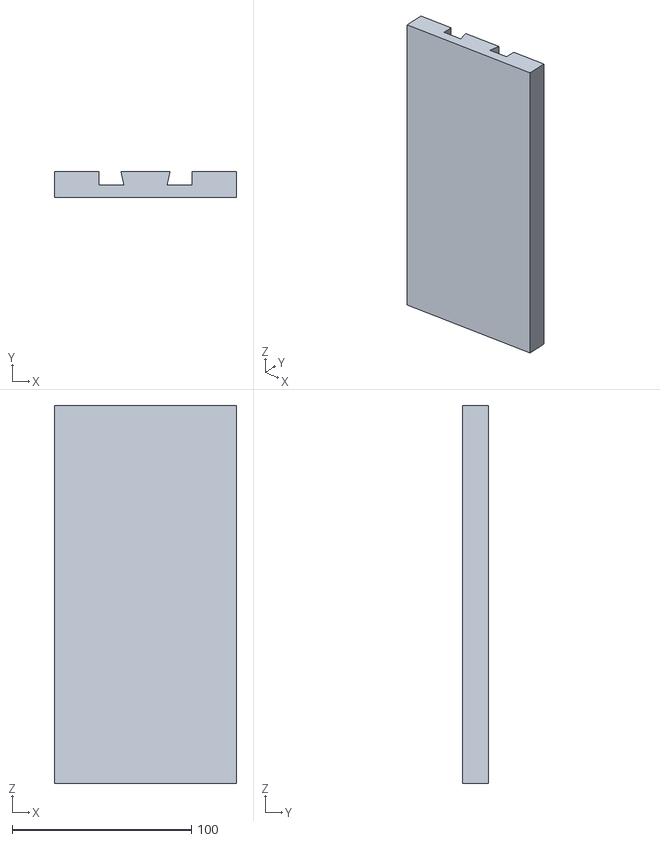
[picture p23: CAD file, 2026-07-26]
Otros archivos/Diseños/Calador/PAredCal2.stl
101.8 x 14.6 x 211.2

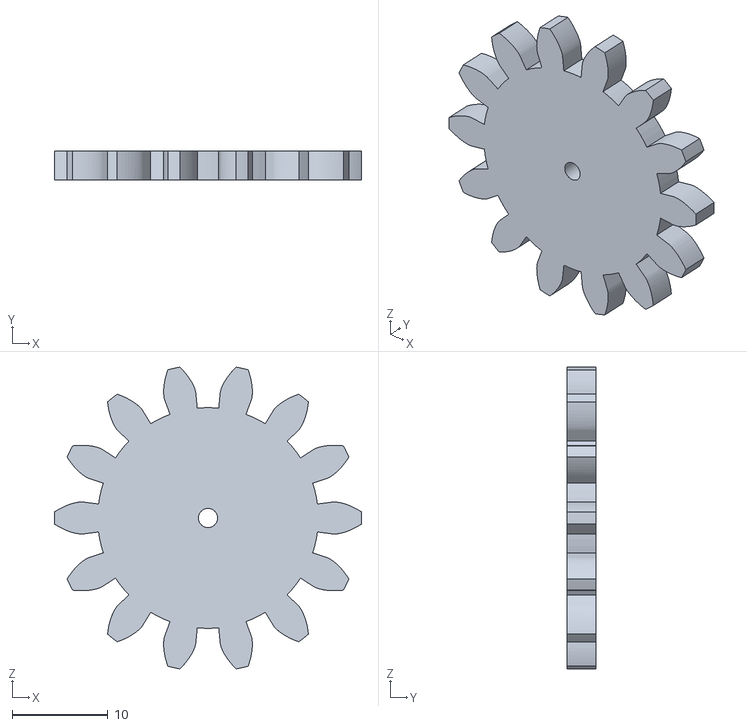
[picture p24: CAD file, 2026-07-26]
Otros archivos/Diseños/Lanzadera/EngranajeLanza.stl
32.0 x 3.00 x 31.5

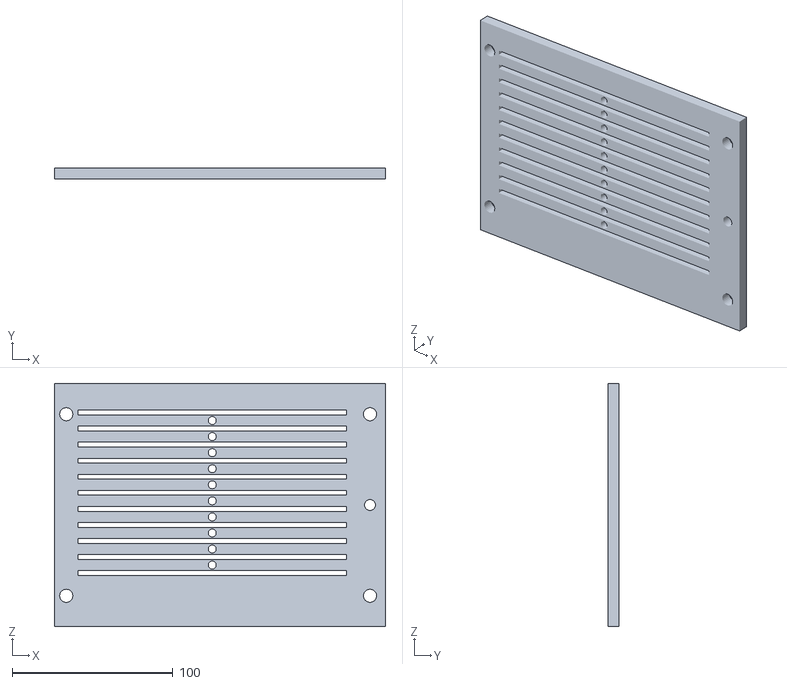
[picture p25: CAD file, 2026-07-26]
Otros archivos/Diseños/Peine/Peine.stl
206.2 x 7.00 x 151.5

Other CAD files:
Archivos/PCB/LIBRERIAS /Huellas/B4B-PH-K-S_LF__SN_/B4B-PH-K-S_LF__SN_.step
Otros archivos/Diseños/Plegador/PAredPlegador1.stl
Archivos/LoomETec-Jacquard/Diseños/Calador/Caladror1.stl
Archivos/LoomETec-Jacquard/Diseños/GuiaEjeX1.stl
Archivos/LoomETec-Jacquard/Diseños/Calador/ActuadorEjeZ.stl
Archivos/LoomETec-Jacquard/Diseños/Calador/Base2.stl
Archivos/LoomETec-Jacquard/Diseños/Calador/Calador2.stl
Archivos/LoomETec-Jacquard/Diseños/Calador/ChasisActuadorEjeZ.stl
Archivos/LoomETec-Jacquard/Diseños/Calador/EngranajeMot.stl
Archivos/LoomETec-Jacquard/Diseños/Calador/EngranajeMovEjeX.stl
Archivos/LoomETec-Jacquard/Diseños/Calador/GuiaEjeX1.stl
Archivos/LoomETec-Jacquard/Diseños/Calador/GuiaEjeX2.stl
Archivos/LoomETec-Jacquard/Diseños/Calador/GuiaEjeX3.stl
Archivos/LoomETec-Jacquard/Diseños/Calador/Pasador.stl
Archivos/LoomETec-Jacquard/Diseños/Calador/Paso1Egranaje-Cadena.stl
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

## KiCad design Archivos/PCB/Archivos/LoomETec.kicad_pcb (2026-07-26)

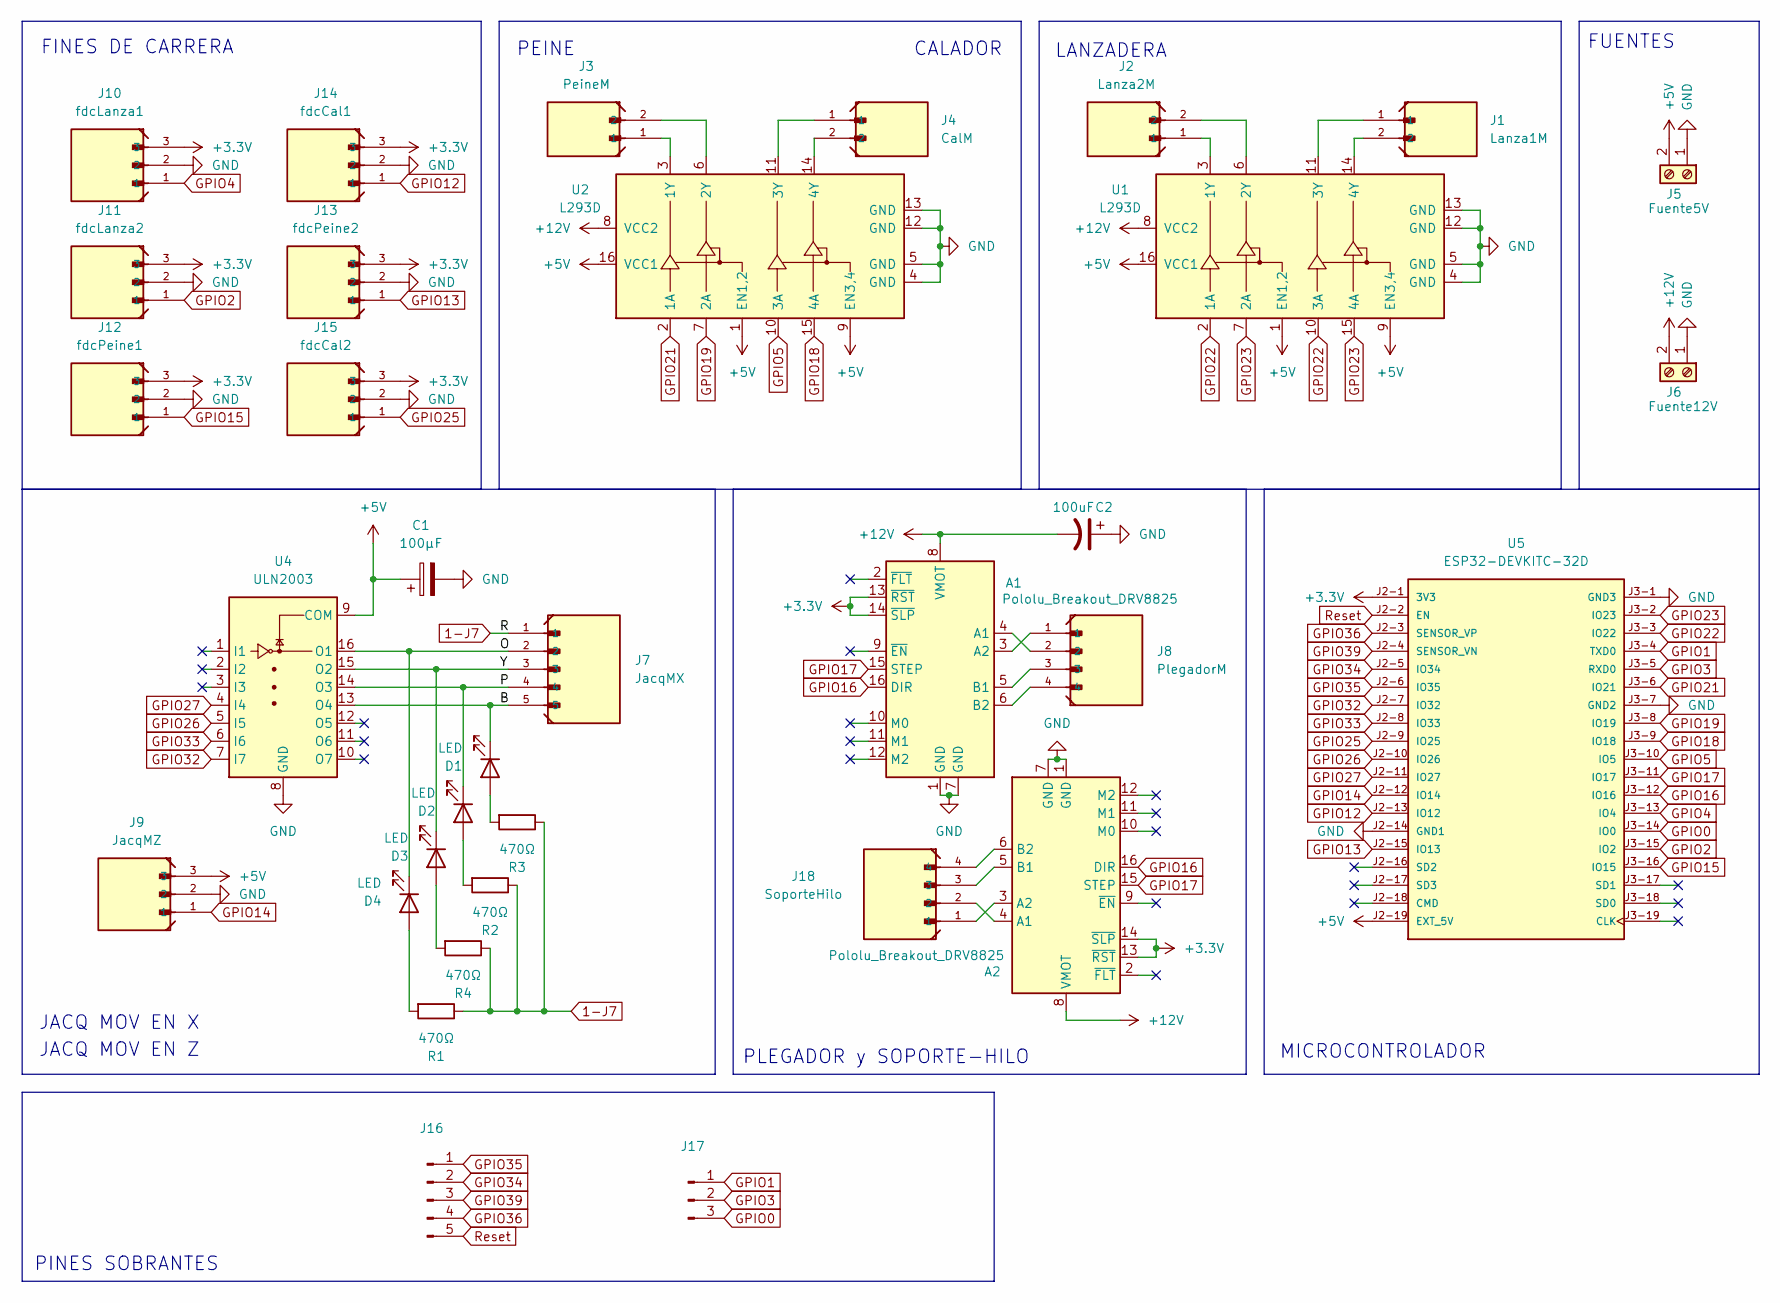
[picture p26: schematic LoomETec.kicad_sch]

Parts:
A1, A2: Pololu_Breakout_DRV8825; DRV8825-PT
C1: 100µF; CP_Radial_D6.3mm_P2.50mm
C2: 100uF; CP_Radial_D6.3mm_P2.50mm
D1, D2, D3, D4: LED; LED_D5.0mm
J1: Lanza1M; JST_XH_B2B-XH-A_1x02_P2.50mm_Vertical
J2: Lanza2M; JST_XH_B2B-XH-A_1x02_P2.50mm_Vertical
J3: PeineM; JST_XH_B2B-XH-A_1x02_P2.50mm_Vertical
J4: CalM; JST_XH_B2B-XH-A_1x02_P2.50mm_Vertical
J5: Fuente5V; TerminalBlock_MaiXu_MX126-5.0-02P_1x02_P5.00mm
J6: Fuente12V; TerminalBlock_MaiXu_MX126-5.0-02P_1x02_P5.00mm
J7: JacqMX; JST_XH_B5B-XH-A_1x05_P2.50mm_Vertical
J8: PlegadorM; JST_XH_B4B-XH-A_1x04_P2.50mm_Vertical
J9: JacqMZ; JST_XH_B3B-XH-A_1x03_P2.50mm_Vertical
J10: fdcLanza1; JST_XH_B3B-XH-A_1x03_P2.50mm_Vertical
J11: fdcLanza2; JST_XH_B3B-XH-A_1x03_P2.50mm_Vertical
J12: fdcPeine1; JST_XH_B3B-XH-A_1x03_P2.50mm_Vertical
J13: fdcPeine2; JST_XH_B3B-XH-A_1x03_P2.50mm_Vertical
J14: fdcCal1; JST_XH_B3B-XH-A_1x03_P2.50mm_Vertical
J15: fdcCal2; JST_XH_B3B-XH-A_1x03_P2.50mm_Vertical
J16: Conn_01x05_Pin; PinHeader_1x05_P2.54mm_Vertical
J17: Conn_01x03_Pin; PinHeader_1x03_P2.54mm_Vertical
J18: SoporteHilo; JST_XH_B4B-XH-A_1x04_P2.50mm_Vertical
R1, R2, R3, R4: 470Ω; R_Axial_DIN0207_L6.3mm_D2.5mm_P10.16mm_Horizontal
U1, U2: L293D; DIP-16_W7.62mm
U4: ULN2003; DIP794W45P254L1969H508Q16
U5: ESP32-DEVKITC-32D; NODEMCU-ESP-32S; PARTREV V4

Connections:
1-J7: J7.1, R1.1, R2.1, R3.1, R4.1
+3.3V: A1.13 (~RST), A1.14 (~SLP), A2.13 (~RST), A2.14 (~SLP), J10.3, J11.3, J12.3, J13.3, J14.3, J15.3, U5.J2-1 (3V3)
+5V: C1.1, J5.2, J9.3, U1.1 (EN1,2), U1.9 (EN3,4), U1.16 (VCC1), U2.1 (EN1,2), U2.9 (EN3,4), U2.16 (VCC1), U4.9 (COM), U5.J2-19 (EXT_5V)
+12V: A1.8 (VMOT), A2.8 (VMOT), C2.2, J6.2, U1.8 (VCC2), U2.8 (VCC2)
/B: D1.1 (K), J7.5, U4.13 (O4)
/O: D4.1 (K), J7.2, U4.16 (O1)
/P: D2.1 (K), J7.4, U4.14 (O3)
/Y: D3.1 (K), J7.3, U4.15 (O2)
GND: A1.1 (GND), A1.7 (GND), A2.1 (GND), A2.7 (GND), C1.2, C2.1, J5.1, J6.1, J9.2, J10.2, J11.2, J12.2, J13.2, J14.2, J15.2, U1.4 (GND), U1.5 (GND), U1.12 (GND), U1.13 (GND), U2.4 (GND), U2.5 (GND), U2.12 (GND), U2.13 (GND), U4.8 (GND), U5.J2-14 (GND1), U5.J3-1 (GND3), U5.J3-7 (GND2)
GPIO0: J17.3, U5.J3-14 (IO0)
GPIO1: J17.1, U5.J3-4 (TXD0)
GPIO2: J11.1, U5.J3-15 (IO2)
GPIO3: J17.2, U5.J3-5 (RXD0)
GPIO4: J10.1, U5.J3-13 (IO4)
GPIO5: U2.10 (3A), U5.J3-10 (IO5)
GPIO12: J14.1, U5.J2-13 (IO12)
GPIO13: J13.1, U5.J2-15 (IO13)
GPIO14: J9.1, U5.J2-12 (IO14)
GPIO15: J12.1, U5.J3-16 (IO15)
GPIO16: A1.16 (DIR), A2.16 (DIR), U5.J3-12 (IO16)
GPIO17: A1.15 (STEP), A2.15 (STEP), U5.J3-11 (IO17)
GPIO18: U2.15 (4A), U5.J3-9 (IO18)
GPIO19: U2.7 (2A), U5.J3-8 (IO19)
GPIO21: U2.2 (1A), U5.J3-6 (IO21)
GPIO22: U1.2 (1A), U1.10 (3A), U5.J3-3 (IO22)
GPIO23: U1.7 (2A), U1.15 (4A), U5.J3-2 (IO23)
GPIO25: J15.1, U5.J2-9 (IO25)
GPIO26: U4.5 (I5), U5.J2-10 (IO26)
GPIO27: U4.4 (I4), U5.J2-11 (IO27)
GPIO32: U4.7 (I7), U5.J2-7 (IO32)
GPIO33: U4.6 (I6), U5.J2-8 (IO33)
GPIO34: J16.2, U5.J2-5 (IO34)
GPIO35: J16.1, U5.J2-6 (IO35)
GPIO36: J16.4, U5.J2-3 (SENSOR_VP)
GPIO39: J16.3, U5.J2-4 (SENSOR_VN)
unnamed: A1.4 (A1), J8.2
unnamed: A1.3 (A2), J8.1
unnamed: A1.5 (B1), J8.3
unnamed: A1.6 (B2), J8.4
unnamed: A2.4 (A1), J18.2
unnamed: A2.3 (A2), J18.1
unnamed: A2.5 (B1), J18.3
unnamed: A2.6 (B2), J18.4
unnamed: D1.2 (A), R3.2
unnamed: D2.2 (A), R2.2
unnamed: D3.2 (A), R4.2
unnamed: D4.2 (A), R1.2
unnamed: J2.1, U1.3 (1Y)
unnamed: J2.2, U1.6 (2Y)
unnamed: J1.1, U1.11 (3Y)
unnamed: J1.2, U1.14 (4Y)
unnamed: J3.1, U2.3 (1Y)
unnamed: J3.2, U2.6 (2Y)
unnamed: J4.1, U2.11 (3Y)
unnamed: J4.2, U2.14 (4Y)
Reset: J16.5, U5.J2-2 (EN)

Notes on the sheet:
LANZADERA
FUENTES
JACQ MOV EN X
PLEGADOR y SOPORTE-HILO
CALADOR
PINES SOBRANTES
FINES DE CARRERA
MICROCONTROLADOR
JACQ MOV EN Z
PEINE

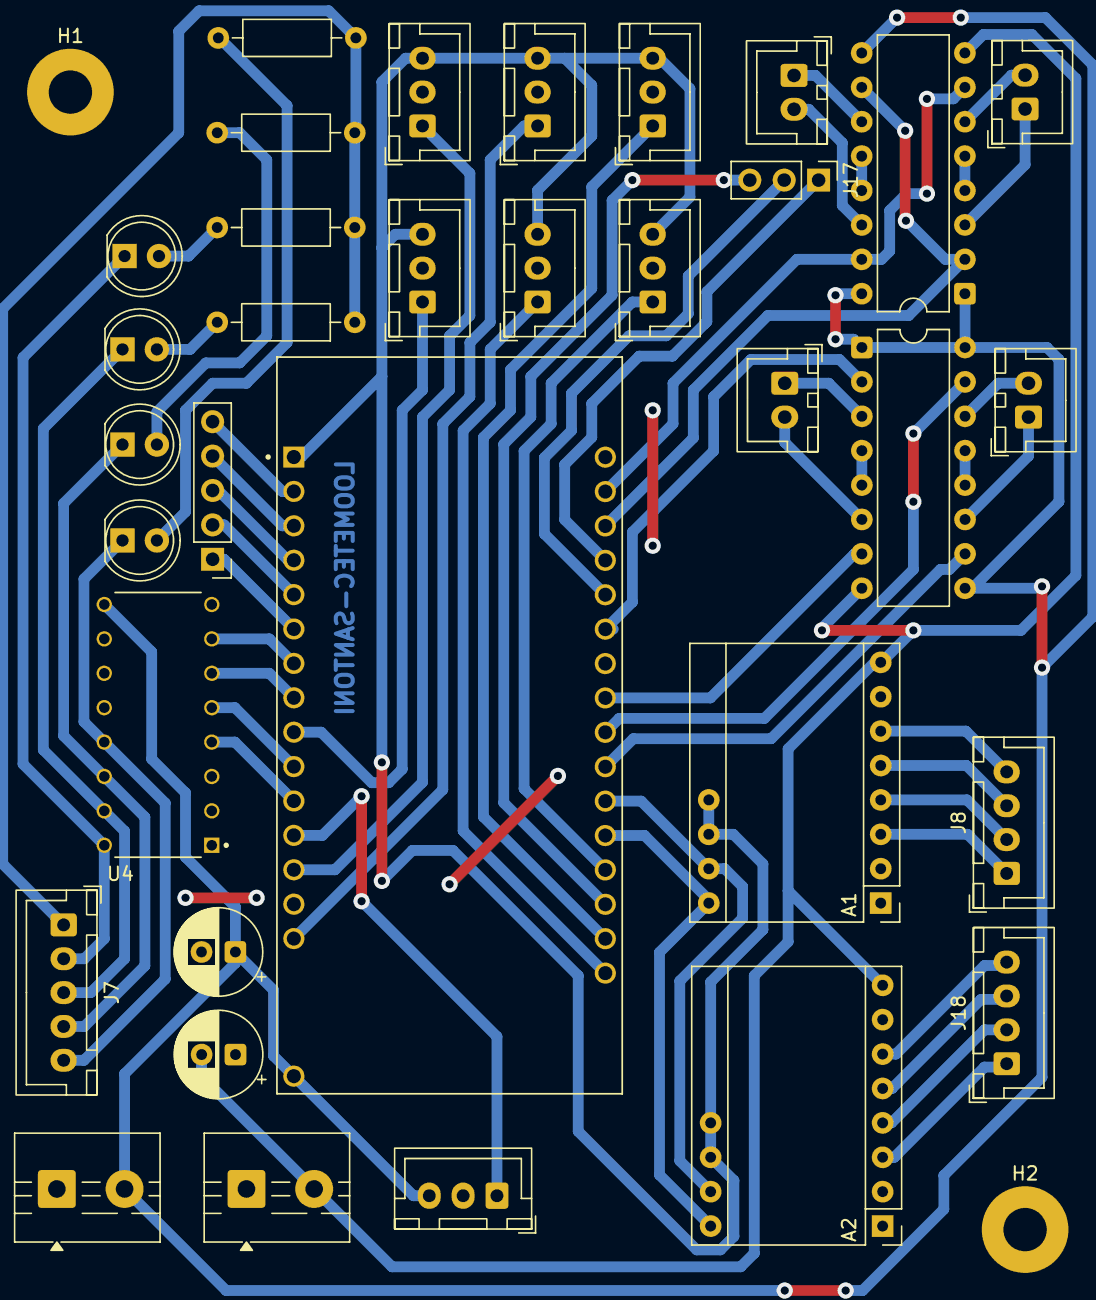
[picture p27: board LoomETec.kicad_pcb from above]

Board: 2 copper layers, 36 parts (0 on the bottom side), 56 nets.

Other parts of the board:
H1, H2: MountingHole_3.2mm_M3_Pad

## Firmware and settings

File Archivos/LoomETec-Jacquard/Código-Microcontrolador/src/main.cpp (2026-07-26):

#include <Arduino.h>
#include <ArduinoJson.h>
#include <WiFi.h>
#include <WiFiClient.h>
#include <PubSubClient.h>
#include <ESP32Servo.h>
#include <esp_task_wdt.h>

// ============================================
// DEFINICIÓN DE PINES - SISTEMA JACQUARD
// ============================================

// Lanzadera (Motor DC con puente H)
#define lanzadera1    23
#define lanzadera2    22
#define enaLanzadera  34    // Pin PWM enable del puente H de la lanzadera
#define fdcLanzadera1  4    // FDC lado izquierdo
#define fdcLanzadera2  2    // FDC lado derecho

// Peine (Motor DC con puente H)
#define peine1        19
#define peine2        21
#define enaPeine      35    // Pin PWM enable del puente H del peine
#define fdcPeine1     15    // FDC peine adelante
#define fdcPeine2     13    // FDC peine atrás

// Plegador (Motor paso a paso con driver A4988/DRV8825)
#define stepPlegador  16
#define dirPlegador   17

// Calador - Eje Y (Motor DC con puente H)
#define ejeY_Up       18    // Dirección subir
#define ejeY_Down      5    // Dirección bajar
#define enaEjeY       36    // Pin PWM enable del puente H del calador  ← NUEVO
#define fdcEjeY_Arriba 12   // FDC posición superior  (antes fdcEjeY1)
#define fdcEjeY_Abajo  25   // FDC posición inferior  (antes fdcEjeY2)

// Eje X - Motor 28BYJ-48 (motor unipolar de 4 fases, sin driver externo)
#define stepX_Pin1    26
#define stepX_Pin2    27
#define stepX_Pin3    33
#define stepX_Pin4    32
// FDC de referencia / home del eje X
#define fdcEjeX_Home  14    // ← reasignado (servoEjeZ se mueve a pin 39)

// Servo eje Z (pistón Jacquard)
#define servoEjeZ_Pin 39    // ← reasignado para liberar pin 14

// ============================================
// CANALES PWM  (ledcSetup / ledcAttachPin)
// ============================================

#define PWM_LANZADERA  0
#define PWM_PEINE      2
#define PWM_EJE_Y      4

// ============================================
// CONFIGURACIÓN DEL SISTEMA JACQUARD
// ============================================

#define NUM_COLUMNAS       31
// Secuencia de pasos del 28BYJ-48 (half-step, 8 fases)
// Da mayor torque y suavidad que full-step
#define PASOS_POR_COLUMNA  512   // pasos half-step entre columnas
#define DELAY_PASO_X_US    1200  // µs entre cada fase del 28BYJ-48

#define SERVO_POS_ABAJO    45    // pistón fuera (hilo queda abajo)
#define SERVO_POS_ARRIBA   135   // pistón dentro (hilo sube)
#define SERVO_DELAY_MS     150   // tiempo para que el servo se mueva

// ============================================
// CONFIGURACIÓN GENERAL
// ============================================

#define CANT_PASOS_PLEGADOR  150
#define DELAY_PASO_PLEGADOR  3000   // µs entre pasos del plegador
#define DELAY_TEJER_MS       500
#define FDC_PRESIONADO       LOW
#define TIEMPO_ESPERA_FDC    15000  // ms máximo esperando un FDC
#define TIEMPO_ESTABILIDAD   200    // ms de pausa tras alcanzar FDC

// Tópicos MQTT
#define TOPICO_EMPEZAR  "empezar"
#define TOPICO_PARAR    "parar"
#define TOPICO_RED      "config/red"
#define TOPICO_VUELTA   "vuelta"
#define TOPICO_PATRON   "config/patron"

// ============================================
// VARIABLES GLOBALES
// ============================================

bool estadoTejiendo = false;
unsigned long vueltas = 0;

String ssid     = "PIPO";
String password = "m1lan3sa";
const char* mqtt_server = "192.168.100.153";
const char* mqtt_user   = "chopo.mqtt";
const char* mqtt_pass   = "m1lan3sa";
#define PUERTO_MQTT 1883

WiFiClient espClient;
PubSubClient client(espClient);
Servo servoZ;

#define MAX_FILAS 500
uint8_t patron[MAX_FILAS][NUM_COLUMNAS];
int numFilas    = 0;
int filaActual  = 0;
bool patronCargado = false;

// Posición lógica actual del eje X (columna 0 … NUM_COLUMNAS-1)
int posicionEjeX = 0;

// Tabla de secuencia half-step para 28BYJ-48
// 4 bobinas, 8 pasos por ciclo
const uint8_t halfStep[8][4] = {
  {1, 0, 0, 0},
  {1, 1, 0, 0},
  {0, 1, 0, 0},
  {0, 1, 1, 0},
  {0, 0, 1, 0},
  {0, 0, 1, 1},
  {0, 0, 0, 1},
  {1, 0, 0, 1}
};

// ============================================
// FUNCIONES DE CONTROL BÁSICO
// ============================================

void parar() {
  estadoTejiendo = false;
  Serial.println("Parando el telar...");

  digitalWrite(lanzadera1, LOW);
  digitalWrite(lanzadera2, LOW);
  digitalWrite(peine1,     LOW);
  digitalWrite(peine2,     LOW);
  digitalWrite(ejeY_Up,    LOW);
  digitalWrite(ejeY_Down,  LOW);

  ledcWrite(PWM_LANZADERA, 0);
  ledcWrite(PWM_PEINE,     0);
  ledcWrite(PWM_EJE_Y,     0);

  // Apagar bobinas del 28BYJ-48 para no calentar
  digitalWrite(stepX_Pin1, LOW);
  digitalWrite(stepX_Pin2, LOW);
  digitalWrite(stepX_Pin3, LOW);
  digitalWrite(stepX_Pin4, LOW);
}

/**
 * Espera hasta que el pin FDC quede en FDC_PRESIONADO.
 * Devuelve false si se supera el timeout o se para el tejido.
 */
bool verificarFDC(int fdcPin) {
  unsigned long t0 = millis();
  Serial.print("Esperando FDC en pin ");
  Serial.println(fdcPin);

  while (digitalRead(fdcPin) != FDC_PRESIONADO) {
    if (millis() - t0 > TIEMPO_ESPERA_FDC) {
      Serial.print("TIMEOUT: FDC no se activó en pin ");
      Serial.println(fdcPin);
      parar();
      return false;
    }
    if (!estadoTejiendo) return false;
    client.loop();
  }

  Serial.println("FDC activado OK");
  return true;
}

// ============================================
// FUNCIONES DEL EJE X (28BYJ-48)
// ============================================

/**
 * Aplica una fase de la secuencia half-step al motor 28BYJ-48.
 * paso: índice 0–7 de la tabla halfStep[]
 */
void aplicarPaso28BYJ(int paso) {
  paso = ((paso % 8) + 8) % 8;  // wrap seguro
  digitalWrite(stepX_Pin1, halfStep[paso][0]);
  digitalWrite(stepX_Pin2, halfStep[paso][1]);
  digitalWrite(stepX_Pin3, halfStep[paso][2]);
  digitalWrite(stepX_Pin4, halfStep[paso][3]);
  delayMicroseconds(DELAY_PASO_X_US);
}

/**
 * Lleva el eje X al home buscando el FDC de referencia.
 * Mueve en sentido antihorario (índice decreciente) hasta activar el FDC.
 */
void homeEjeX() {
  Serial.println("HOME Eje X...");

  int paso = 0;
  unsigned long t0 = millis();

  while (digitalRead(fdcEjeX_Home) != FDC_PRESIONADO) {
    paso = (paso + 7) % 8;  // retroceder una fase (antihorario)
    aplicarPaso28BYJ(paso);

    if (millis() - t0 > TIEMPO_ESPERA_FDC) {
      Serial.println("TIMEOUT: Home Eje X fallido");
      parar();
      return;
    }
    if (!estadoTejiendo) return;
  }

  // Apagar bobinas al llegar
  digitalWrite(stepX_Pin1, LOW);
  digitalWrite(stepX_Pin2, LOW);
  digitalWrite(stepX_Pin3, LOW);
  digitalWrite(stepX_Pin4, LOW);

  posicionEjeX = 0;
  delay(TIEMPO_ESTABILIDAD);
  Serial.println("Eje X en HOME (columna 0)");
}

/**
 * Mueve el eje X a la columna indicada (0 … NUM_COLUMNAS-1).
 * Siempre hace home primero para garantizar posición absoluta.
 */
void moverEjeX(int columna) {
  if (columna < 0 || columna >= NUM_COLUMNAS) return;

  homeEjeX();
  if (!estadoTejiendo) return;
  if (columna == 0) return;

  int totalPasos = columna * PASOS_POR_COLUMNA;
  int paso = 0;

  for (int i = 0; i < totalPasos; i++) {
    paso = (paso + 1) % 8;  // avanzar (horario)
    aplicarPaso28BYJ(paso);
    if (!estadoTejiendo) return;
  }

  // Apagar bobinas al terminar
  digitalWrite(stepX_Pin1, LOW);
  digitalWrite(stepX_Pin2, LOW);
  digitalWrite(stepX_Pin3, LOW);
  digitalWrite(stepX_Pin4, LOW);

  posicionEjeX = columna;
  delay(TIEMPO_ESTABILIDAD);
}

// ============================================
// FUNCIÓN DEL SERVO Z (PISTÓN JACQUARD)
// ============================================

/**
 * valor == 1 → hilo SUBE  → servo esconde pistón (ARRIBA)
 * valor == 0 → hilo BAJA  → servo introduce pistón (ABAJO)
 */
void configurarServoZ(uint8_t valor) {
  int posicion = (valor == 1) ? SERVO_POS_ARRIBA : SERVO_POS_ABAJO;
  servoZ.write(posicion);
  delay(SERVO_DELAY_MS);
}

// ============================================
// FUNCIONES DEL CALADOR (EJE Y)
// ============================================

/**
 * Sube el calador hasta el FDC superior.
 */
bool subirCalador() {
  Serial.println("Subiendo calador...");

  digitalWrite(ejeY_Up,   HIGH);
  digitalWrite(ejeY_Down, LOW);
  ledcWrite(PWM_EJE_Y, 200);

  if (!verificarFDC(fdcEjeY_Arriba)) return false;

  ledcWrite(PWM_EJE_Y, 0);
  digitalWrite(ejeY_Up,   LOW);
  digitalWrite(ejeY_Down, LOW);
  delay(TIEMPO_ESTABILIDAD);

  Serial.println("Calador arriba OK");
  return true;
}

/**
 * Baja el calador hasta el FDC inferior.
 */
bool bajarCalador() {
  Serial.println("Bajando calador...");

  digitalWrite(ejeY_Up,   LOW);
  digitalWrite(ejeY_Down, HIGH);
  ledcWrite(PWM_EJE_Y, 200);

  if (!verificarFDC(fdcEjeY_Abajo)) return false;

  ledcWrite(PWM_EJE_Y, 0);
  digitalWrite(ejeY_Up,   LOW);
  digitalWrite(ejeY_Down, LOW);
  delay(TIEMPO_ESTABILIDAD);

  Serial.println("Calador abajo OK");
  return true;
}

// ============================================
// CONFIGURACIÓN DE LA CALADA (pasos 3-6)
// ============================================

/**
 * Configura la calada para la fila indicada del patrón.
 *
 * Secuencia interna:
 *   3. Eje X se alinea con cada hilo (columna 0 a 30) usando 28BYJ-48.
 *   4. Servo Z sube o baja el pistón según el valor del patrón.
 *   5. Se repite para las 31 columnas.
 *   6. Motor DC sube los hilos seleccionados hasta el FDC superior.
 *
 * Al finalizar el tejido de la pasada, el caller debe llamar a bajarCalador().
 */
bool configurarCalada(int fila) {
  if (!patronCargado || fila < 0 || fila >= numFilas) {
    Serial.println("ERROR: Patrón no cargado o fila fuera de rango");
    parar();
    return false;
  }

  Serial.print("Configurando calada – fila ");
  Serial.println(fila);

  // PASO 3+4+5: posicionar servo en cada columna
  for (int col = 0; col < NUM_COLUMNAS; col++) {
    if (!estadoTejiendo) return false;

    moverEjeX(col);
    if (!estadoTejiendo) return false;

    uint8_t valor = patron[fila][col];
    configurarServoZ(valor);

    Serial.print(valor);
    if (col < NUM_COLUMNAS - 1) Serial.print(",");

    client.loop();
  }
  Serial.println();

  // Volver al home del eje X antes de subir el calador
  homeEjeX();
  if (!estadoTejiendo) return false;

  // PASO 6: subir calador (hilos seleccionados suben)
  if (!subirCalador()) return false;

  return true;
}

// ============================================
// PROCESAMIENTO DE PATRÓN JSON
// ============================================

bool procesarPatronJSON(const char* jsonString) {
  DynamicJsonDocument doc(8192);

  DeserializationError error = deserializeJson(doc, jsonString);
  if (error) {
    Serial.print("Error parseando JSON: ");
    Serial.println(error.c_str());
    return false;
  }

  if (!doc.containsKey("dimensiones") || !doc.containsKey("datos")) {
    Serial.println("JSON inválido: faltan 'dimensiones' o 'datos'");
    return false;
  }

  JsonArray dimensiones = doc["dimensiones"];
  int cols  = dimensiones[0];
  int filas = dimensiones[1];

  if (cols != NUM_COLUMNAS) {
    Serial.printf("ERROR: patrón con %d columnas, se esperan %d\n", cols, NUM_COLUMNAS);
    return false;
  }

  if (filas > MAX_FILAS) {
    Serial.printf("ERROR: patrón con %d filas, máximo %d\n", filas, MAX_FILAS);
    return false;
  }

  JsonArray datos = doc["datos"];
  numFilas = 0;

  for (JsonArray fila : datos) {
    if (numFilas >= MAX_FILAS) break;
    int col = 0;
    for (int valor : fila) {
      if (col >= NUM_COLUMNAS) break;
      patron[numFilas][col] = (valor != 0) ? 1 : 0;
      col++;
    }
    numFilas++;
  }

  Serial.printf("Patrón cargado: %d filas x %d columnas\n", numFilas, NUM_COLUMNAS);
  filaActual = 0;
  patronCargado = true;
  return true;
}

// ============================================
// FUNCIÓN PRINCIPAL DE TEJIDO
// Secuencia completa de 1 ciclo (2 pasadas de lanzadera)
// ============================================

void tejer() {
  if (!patronCargado) {
    Serial.println("ERROR: No hay patrón cargado.");
    parar();
    return;
  }

  // ─────────────────────────────────────────
  // ══ PRIMERA PASADA ══
  // ─────────────────────────────────────────
  Serial.printf("=== PRIMERA PASADA – fila %d/%d ===\n", filaActual, numFilas);

  // PASOS 3-6: configurar calada (mueve eje X, servo Z, sube calador)
  if (!configurarCalada(filaActual)) return;
  client.loop();

  // PASO 7: Lanzadera de izquierda a derecha → espera FDC lado derecho
  Serial.println("Lanzadera → derecha");
  digitalWrite(lanzadera1, HIGH);
  digitalWrite(lanzadera2, LOW);
  ledcWrite(PWM_LANZADERA, 200);
  if (!verificarFDC(fdcLanzadera2)) return;   // FDC del lado destino
  ledcWrite(PWM_LANZADERA, 0);
  digitalWrite(lanzadera1, LOW);
  digitalWrite(lanzadera2, LOW);
  delay(TIEMPO_ESTABILIDAD);
  client.loop();

  // PASO 8a: Peine adelante (aprieta el hilo)
  Serial.println("Peine adelante");
  digitalWrite(peine1, HIGH);
  digitalWrite(peine2, LOW);
  ledcWrite(PWM_PEINE, 200);
  if (!verificarFDC(fdcPeine1)) return;
  ledcWrite(PWM_PEINE, 0);
  digitalWrite(peine1, LOW);
  digitalWrite(peine2, LOW);
  delay(TIEMPO_ESTABILIDAD);
  client.loop();

  // PASO 8b: Peine atrás (vuelve a posición inicial)
  Serial.println("Peine atrás");
  digitalWrite(peine1, LOW);
  digitalWrite(peine2, HIGH);
  ledcWrite(PWM_PEINE, 200);
  if (!verificarFDC(fdcPeine2)) return;
  ledcWrite(PWM_PEINE, 0);
  digitalWrite(peine1, LOW);
  digitalWrite(peine2, LOW);
  delay(TIEMPO_ESTABILIDAD);
  client.loop();

  // PASO 9: Bajar calador (los hilos seleccionados vuelven abajo)
  if (!bajarCalador()) return;
  client.loop();

  // PASO 10: Plegador avanza un incremento
  Serial.println("Plegador");
  digitalWrite(dirPlegador, HIGH);
  for (int i = 0; i < CANT_PASOS_PLEGADOR; i++) {
    digitalWrite(stepPlegador, HIGH);
    delayMicroseconds(DELAY_PASO_PLEGADOR);
    digitalWrite(stepPlegador, LOW);
    delayMicroseconds(DELAY_PASO_PLEGADOR);
  }
  client.loop();

  // Avanzar a la siguiente fila del patrón
  filaActual++;
  if (filaActual >= numFilas) {
    Serial.println("Patrón completado → reiniciando desde fila 0");
    filaActual = 0;
  }

  // ─────────────────────────────────────────
  // ══ SEGUNDA PASADA ══
  // ─────────────────────────────────────────
  Serial.printf("=== SEGUNDA PASADA – fila %d/%d ===\n", filaActual, numFilas);

  // PASOS 3-6: nueva calada para la siguiente fila
  if (!configurarCalada(filaActual)) return;
  client.loop();

  // PASO 7: Lanzadera de derecha a izquierda → espera FDC lado izquierdo
  Serial.println("Lanzadera → izquierda");
  digitalWrite(lanzadera1, LOW);
  digitalWrite(lanzadera2, HIGH);
  ledcWrite(PWM_LANZADERA, 200);
  if (!verificarFDC(fdcLanzadera1)) return;   // FDC del lado destino
  ledcWrite(PWM_LANZADERA, 0);
  digitalWrite(lanzadera1, LOW);
  digitalWrite(lanzadera2, LOW);
  delay(TIEMPO_ESTABILIDAD);
  client.loop();

  // PASO 8a: Peine adelante
  Serial.println("Peine adelante");
  digitalWrite(peine1, HIGH);
  digitalWrite(peine2, LOW);
  ledcWrite(PWM_PEINE, 200);
  if (!verificarFDC(fdcPeine1)) return;
  ledcWrite(PWM_PEINE, 0);
  digitalWrite(peine1, LOW);
  digitalWrite(peine2, LOW);
  delay(TIEMPO_ESTABILIDAD);
  client.loop();

  // PASO 8b: Peine atrás
  Serial.println("Peine atrás");
  digitalWrite(peine1, LOW);
  digitalWrite(peine2, HIGH);
  ledcWrite(PWM_PEINE, 200);
  if (!verificarFDC(fdcPeine2)) return;
  ledcWrite(PWM_PEINE, 0);
  digitalWrite(peine1, LOW);
  digitalWrite(peine2, LOW);
  delay(TIEMPO_ESTABILIDAD);
  client.loop();

  // PASO 9: Bajar calador
  if (!bajarCalador()) return;
  client.loop();

  // PASO 10: Plegador
  Serial.println("Plegador");
  digitalWrite(dirPlegador, HIGH);
  for (int i = 0; i < CANT_PASOS_PLEGADOR; i++) {
    digitalWrite(stepPlegador, HIGH);
    delayMicroseconds(DELAY_PASO_PLEGADOR);
    digitalWrite(stepPlegador, LOW);
    delayMicroseconds(DELAY_PASO_PLEGADOR);
  }
  client.loop();

  // ─────────────────────────────────────────
  Serial.println("=== FIN DE CICLO COMPLETO ===");
  vueltas++;
  client.publish(TOPICO_VUELTA, String(vueltas).c_str());

  // Avanzar a la siguiente fila para el próximo ciclo
  filaActual++;
  if (filaActual >= numFilas) {
    Serial.println("Patrón completado → reiniciando desde fila 0");
    filaActual = 0;
  }
}

// ============================================
// WIFI Y MQTT
// ============================================

void setup_wifi() {
  delay(10);
  Serial.print("Conectando a ");
  Serial.println(ssid);
  WiFi.mode(WIFI_STA);
  WiFi.begin(ssid, password);
  while (WiFi.status() != WL_CONNECTED) {
    delay(500);
    Serial.print(".");
  }
  Serial.print("\nWiFi conectado – IP: ");
  Serial.println(WiFi.localIP());
}

void reconnect() {
  while (!client.connected()) {
    Serial.print("Conectando MQTT...");
    String clientId = "ESP32Client-" + String(random(0xffff), HEX);
    if (client.connect(clientId.c_str(), mqtt_user, mqtt_pass)) {
      Serial.println("conectado");
      client.subscribe(TOPICO_PARAR);
      client.subscribe(TOPICO_EMPEZAR);
      client.subscribe(TOPICO_RED);
      client.subscribe(TOPICO_PATRON);
    } else {
      Serial.printf("falló rc=%d, reintentando en 5s\n", client.state());
      delay(5000);
    }
  }
}

void callback(char* topic, byte* payload, unsigned int length) {
  Serial.print("Mensaje [");
  Serial.print(topic);
  Serial.print("]: ");

  char mensaje[length + 1];
  memcpy(mensaje, payload, length);
  mensaje[length] = '\0';
  Serial.println(mensaje);

  if (strcmp(topic, TOPICO_EMPEZAR) == 0 && payload[0] == '1') {
    if (patronCargado) {
      estadoTejiendo = true;
      Serial.println("Iniciando tejido...");
    } else {
      Serial.println("ERROR: No se puede iniciar sin patrón cargado");
    }
  }
  else if (strcmp(topic, TOPICO_PARAR) == 0 && payload[0] == '1') {
    parar();
  }
  else if (strcmp(topic, TOPICO_RED) == 0) {
    StaticJsonDocument<256> doc;
    if (!deserializeJson(doc, payload)) {
      ssid     = doc["ssid"].as<String>();
      password = doc["password"].as<String>();
      Serial.println("Nueva red recibida, reconectando...");
      setup_wifi();
      reconnect();
    }
  }
  else if (strcmp(topic, TOPICO_PATRON) == 0) {
    Serial.println("Recibiendo patrón JSON...");
    StaticJsonDocument<512> docWrapper;
    if (deserializeJson(docWrapper, payload)) {
      Serial.println("Error parseando wrapper del patrón");
      return;
    }
    const char* content = docWrapper["content"];
    if (content == nullptr) {
      Serial.println("ERROR: falta campo 'content'");
      return;
    }
    if (procesarPatronJSON(content)) {
      Serial.println("✓ Patrón cargado exitosamente");
      filaActual = 0;
    } else {
      Serial.println("✗ Error al cargar el patrón");
    }
  }
}

// ============================================
// SETUP
// ============================================

void setup() {
  Serial.begin(115200);
  Serial.println("\n=== TELAR JACQUARD ESP32 v3.0 ===");

  // --- Lanzadera ---
  pinMode(lanzadera1,    OUTPUT);
  pinMode(lanzadera2,    OUTPUT);
  pinMode(fdcLanzadera1, INPUT_PULLUP);
  pinMode(fdcLanzadera2, INPUT_PULLUP);
  ledcSetup(PWM_LANZADERA, 5000, 8);
  ledcAttachPin(enaLanzadera, PWM_LANZADERA);

  // --- Peine ---
  pinMode(peine1,    OUTPUT);
  pinMode(peine2,    OUTPUT);
  pinMode(fdcPeine1, INPUT_PULLUP);
  pinMode(fdcPeine2, INPUT_PULLUP);
  ledcSetup(PWM_PEINE, 5000, 8);
  ledcAttachPin(enaPeine, PWM_PEINE);

  // --- Plegador ---
  pinMode(stepPlegador, OUTPUT);
  pinMode(dirPlegador,  OUTPUT);

  // --- Eje X (28BYJ-48) ---
  pinMode(stepX_Pin1,   OUTPUT);
  pinMode(stepX_Pin2,   OUTPUT);
  pinMode(stepX_Pin3,   OUTPUT);
  pinMode(stepX_Pin4,   OUTPUT);
  pinMode(fdcEjeX_Home, INPUT_PULLUP);
  // Apagar bobinas al inicio
  digitalWrite(stepX_Pin1, LOW);
  digitalWrite(stepX_Pin2, LOW);
  digitalWrite(stepX_Pin3, LOW);
  digitalWrite(stepX_Pin4, LOW);

  // --- Servo Z ---
  servoZ.attach(servoEjeZ_Pin);
  servoZ.write(SERVO_POS_ABAJO);

  // --- Calador (Eje Y) ---
  pinMode(ejeY_Up,        OUTPUT);
  pinMode(ejeY_Down,      OUTPUT);
  pinMode(fdcEjeY_Arriba, INPUT_PULLUP);
  pinMode(fdcEjeY_Abajo,  INPUT_PULLUP);
  ledcSetup(PWM_EJE_Y, 5000, 8);
  ledcAttachPin(enaEjeY, PWM_EJE_Y);

  // --- WiFi y MQTT ---
  setup_wifi();
  client.setServer(mqtt_server, PUERTO_MQTT);
  client.setCallback(callback);
  client.setBufferSize(16384);

  // --- Home inicial ---
  estadoTejiendo = true;   // habilitamos movimiento solo para el home
  homeEjeX();
  estadoTejiendo = false;

  // Asegurarse de que el calador esté abajo al arrancar
  // (sin esto podría arrancar a mitad de recorrido)
  estadoTejiendo = true;
  bajarCalador();
  estadoTejiendo = false;

  Serial.println("Sistema listo. Esperando patrón vía MQTT...");
}

// ============================================
// LOOP
// ============================================

void loop() {
  if (!client.connected()) {
    reconnect();
  }
  client.loop();

  if (estadoTejiendo) {
    delay(DELAY_TEJER_MS);
    tejer();
  }

  delay(100);
}

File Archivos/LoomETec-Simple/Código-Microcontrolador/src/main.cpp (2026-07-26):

#include <Arduino.h>
#include <ArduinoJson.h>
#include <WiFi.h>
#include <WiFiClient.h>
#include <PubSubClient.h>
#include <esp_task_wdt.h>

// Pines Lanzadera
#define lanzadera1 23
#define lanzadera2 22
#define fdcLanzadera1 4
#define fdcLanzadera2 2

// Pines Peine
#define peine1 19
#define peine2 21
#define fdcPeine1 15
#define fdcPeine2 13

// Pines Plegador 
#define stepPlegador 16
#define dirPlegador 17

// Pines Motor Calador 
#define caladores1 18
#define caladores2 5
#define fdcCaladores 12  

// Canales PWM
#define PWM_LANZADERA 0
#define PWM_CALADORES 1
#define PWM_PEINE 2

// Configuración
#define CANT_PASOS 150
#define DELAY_PASO 3000 
#define DELAY_TEJER 500
#define FDC_PRESIONADO LOW
#define TIEMPO_ESPERA_FDC 15000
#define TIEMPO_ESTABILIDAD 200

// Tópicos MQTT
#define TOPICO_EMPEZAR "empezar"
#define TOPICO_PARAR "parar"
#define TOPICO_RED "config/red"
#define TOPICO_VUELTA "vuelta"

bool estadoTejiendo = false;
unsigned long vueltas = 0;

String ssid = "PIPO";
String password = "m1lan3sa";
const char* mqtt_server = "192.168.100.153";
const char* mqtt_user = "chopo.mqtt";
const char* mqtt_pass = "m1lan3sa";
#define PUERTO_MQTT 1883

WiFiClient espClient;
PubSubClient client(espClient);

void parar() {
  estadoTejiendo = false;
  Serial.println("Parando el telar...");
  
  // Apagar todos los motores
  digitalWrite(lanzadera1, LOW);
  digitalWrite(lanzadera2, LOW);
  digitalWrite(caladores1, LOW);
  digitalWrite(caladores2, LOW);
  digitalWrite(peine1, LOW);
  digitalWrite(peine2, LOW);
  
  ledcWrite(PWM_LANZADERA, 0);
  ledcWrite(PWM_CALADORES, 0);
  ledcWrite(PWM_PEINE, 0);
}

bool verificarFDC(int fdcPin) {
  unsigned long t0 = millis();
  Serial.print("Esperando FDC en pin: ");
  Serial.println(fdcPin);
  
  while (digitalRead(fdcPin) != FDC_PRESIONADO) {
    if (millis() - t0 > TIEMPO_ESPERA_FDC) {
      Serial.println("FDC no se activó, saliendo del bucle. Pin: " + String(fdcPin));
      parar();
      return false;
    }
    if (!estadoTejiendo) return false;
    client.loop();
  }
  
  Serial.println("FDC activado");
  return true;
}

void setup_wifi() {
  delay(10);
  Serial.println();
  Serial.print("Conectando a ");
  Serial.println(ssid);

  WiFi.mode(WIFI_STA);
  WiFi.begin(ssid.c_str(), password.c_str());

  while (WiFi.status() != WL_CONNECTED) {
    delay(500);
    Serial.print(".");
  }

  randomSeed(micros());
  Serial.println("");
  Serial.println("WiFi conectado");
  Serial.println("IP: ");
  Serial.println(WiFi.localIP());
}

void reconnect() {
  while (!client.connected()) {
    Serial.print("Intentando conexión MQTT...");
    String clientId = "ESP32Client-";
    clientId += String(random(0xffff), HEX);
    
    if (client.connect(clientId.c_str(), mqtt_user, mqtt_pass)) {
      Serial.println("conectado");
      client.subscribe(TOPICO_PARAR);
      client.subscribe(TOPICO_EMPEZAR);
      client.subscribe(TOPICO_RED);
    } else {
      Serial.print("falló, rc=");
      Serial.print(client.state());
      Serial.println(" reintentando en 5 segundos");
      delay(5000);
    }
  }
}

void callback(char* topic, byte* payload, unsigned int length) {
  Serial.print("Mensaje recibido [");
  Serial.print(topic);
  Serial.print("]: ");
  
  if (strcmp(topic, TOPICO_EMPEZAR) == 0 && payload[0] == '1') {
    estadoTejiendo = true;
    Serial.println("Iniciando telar");
  } else if (strcmp(topic, TOPICO_PARAR) == 0 && payload[0] == '1') {
    parar();
  } else if (strcmp(topic, TOPICO_RED) == 0) {
    StaticJsonDocument<256> doc;
    DeserializationError error = deserializeJson(doc, payload);
    if (!error) {
      ssid = doc["ssid"].as<String>();
      password = doc["password"].as<String>();
      Serial.println("Recibido SSID y PASSWORD, conectando...");
      setup_wifi();
      reconnect();
    } else {
      Serial.println("Error al parsear JSON");
    }
  }
}

void tejer() {
  // Paso 1: Caladores (posición 1)
  digitalWrite(caladores1, HIGH);
  digitalWrite(caladores2, LOW);
  ledcWrite(PWM_CALADORES, 200);
  if (!verificarFDC(fdcCaladores)) return;
  ledcWrite(PWM_CALADORES, 0);
  digitalWrite(caladores1, LOW);
  delay(TIEMPO_ESTABILIDAD);
  client.loop();

  // Paso 2: Lanzadera ida
  digitalWrite(lanzadera1, HIGH);
  digitalWrite(lanzadera2, LOW);
  ledcWrite(PWM_LANZADERA, 200);
  if (!verificarFDC(fdcLanzadera1)) return;
  ledcWrite(PWM_LANZADERA, 0);
  digitalWrite(lanzadera1, LOW);
  delay(TIEMPO_ESTABILIDAD);
  client.loop();

  // Paso 3: Peine adelante
  digitalWrite(peine1, HIGH);
  digitalWrite(peine2, LOW);
  ledcWrite(PWM_PEINE, 200);
  if (!verificarFDC(fdcPeine1)) return;
  ledcWrite(PWM_PEINE, 0);
  digitalWrite(peine1, LOW);
  delay(TIEMPO_ESTABILIDAD);
  client.loop();

  // Paso 4: Peine atrás
  digitalWrite(peine1, LOW);
  digitalWrite(peine2, HIGH);
  ledcWrite(PWM_PEINE, 200);
  if (!verificarFDC(fdcPeine2)) return;
  ledcWrite(PWM_PEINE, 0);
  digitalWrite(peine2, LOW);
  delay(TIEMPO_ESTABILIDAD);
  client.loop();

  // Paso 5: Plegador
  digitalWrite(dirPlegador, HIGH);
  for (int i = 0; i < CANT_PASOS; i++) {
    digitalWrite(stepPlegador, HIGH);
    delayMicroseconds(DELAY_PASO);
    digitalWrite(stepPlegador, LOW);
    delayMicroseconds(DELAY_PASO);
  }
  client.loop();

  // Paso 6: Caladores (posición 2)
  digitalWrite(caladores1, LOW);
  digitalWrite(caladores2, HIGH);
  ledcWrite(PWM_CALADORES, 200);
  if (!verificarFDC(fdcCaladores)) return;
  ledcWrite(PWM_CALADORES, 0);
  digitalWrite(caladores2, LOW);
  delay(TIEMPO_ESTABILIDAD);
  client.loop();

  // Paso 7: Lanzadera vuelta
  digitalWrite(lanzadera1, LOW);
  digitalWrite(lanzadera2, HIGH);
  ledcWrite(PWM_LANZADERA, 200);
  if (!verificarFDC(fdcLanzadera2)) return;
  ledcWrite(PWM_LANZADERA, 0);
  digitalWrite(lanzadera2, LOW);
  delay(TIEMPO_ESTABILIDAD);
  client.loop();

  // Paso 8: Peine adelante
  digitalWrite(peine1, HIGH);
  digitalWrite(peine2, LOW);
  ledcWrite(PWM_PEINE, 200);
  if (!verificarFDC(fdcPeine1)) return;
  ledcWrite(PWM_PEINE, 0);
  digitalWrite(peine1, LOW);
  delay(TIEMPO_ESTABILIDAD);
  client.loop();

  // Paso 9: Peine atrás
  digitalWrite(peine1, LOW);
  digitalWrite(peine2, HIGH);
  ledcWrite(PWM_PEINE, 200);
  if (!verificarFDC(fdcPeine2)) return;
  ledcWrite(PWM_PEINE, 0);
  digitalWrite(peine2, LOW);
  delay(TIEMPO_ESTABILIDAD);
  client.loop();

  // Paso 10: Plegador
  digitalWrite(dirPlegador, HIGH);
  for (int i = 0; i < CANT_PASOS; i++) {
    digitalWrite(stepPlegador, HIGH);
    delayMicroseconds(DELAY_PASO);
    digitalWrite(stepPlegador, LOW);
    delayMicroseconds(DELAY_PASO);
  }
  client.loop();

  vueltas++;
  Serial.print("Vuelta completada: ");
  Serial.println(vueltas);
  client.publish(TOPICO_VUELTA, String(vueltas).c_str());
}
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

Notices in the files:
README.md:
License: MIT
